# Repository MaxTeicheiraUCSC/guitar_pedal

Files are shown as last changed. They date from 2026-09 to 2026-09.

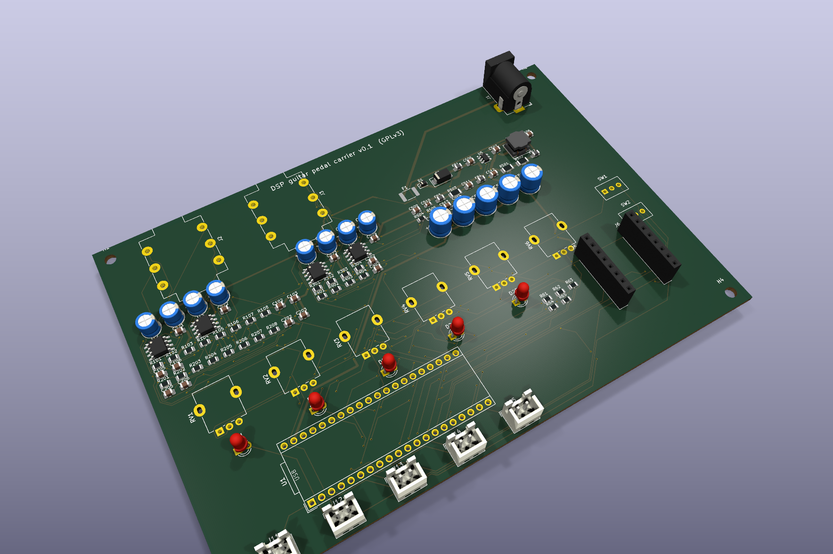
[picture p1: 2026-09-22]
hardware/kicad/out/pedal_3d_iso.png

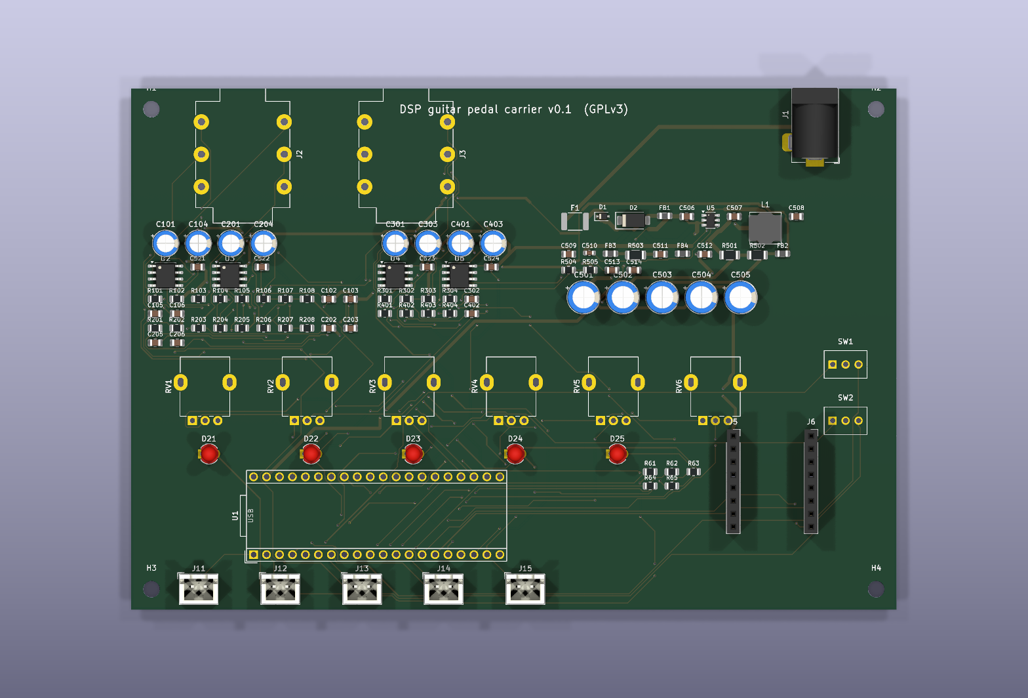
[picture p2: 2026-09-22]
hardware/kicad/out/pedal_3d_top.png

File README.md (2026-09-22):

# guitar_pedal — DSP multi-effect (tremolo · delay · reverb · fuzz)

Daisy Seed3 + ESP32-C3 stereo pedal with a reorderable four-effect chain, five
momentary footswitches, a shared six-knob bank, global high/low-cut toggles, and
BLE-MIDI / WiFi web-UI control. Design rationale, research and the phased plan are
in [`docs/design.md`](docs/design.md); the control protocol in [`docs/midi-map.md`](docs/midi-map.md).

```
firmware/dsp/      portable DSP core (header-only C++17) — shared by the pedal and the emulator
firmware/daisy/    Seed3 wrapper: audio callback, switches, knobs, UART-MIDI, presets   [unverified: no ARM toolchain here]
firmware/esp32/    C3 bridge: BLE-MIDI + WiFi AP web UI ⇄ UART-MIDI                   [unverified: no ESP toolchain here]
web/               single-file web UI served by the ESP32
emulator/          macOS emulator: `emu` offline CLI, hardware model, JUCE front panel (Standalone + VST3), tests
hardware/spice/    ngspice reference of the Seed3 instrument I/O stages + validation harness
hardware/kicad/    carrier board (not started)
docs/              design.md, midi-map.md
```

## Build & test (macOS)

```sh
cd emulator && cmake -B build -DCMAKE_BUILD_TYPE=Release && cmake --build build -j8
./build/dsp_tests                                   # 45 property tests
./build/emu --list                                  # parameter tables + CC numbers
./build/emu --in guitar.wav --out fx.wav --enable 0,1,2,3 --order 3,0,1,2 --hw --cpu
cmake -B build-juce -DPEDAL_BUILD_JUCE=ON && cmake --build build-juce -j8   # JUCE app + VST3 (fetches JUCE 8.0.9)
cmake -B build-juce -DPEDAL_BUILD_JUCE=ON -DPEDAL_HARNESS=ON && ./build-juce/juce/PedalHarness_artefacts/Release/PedalHarness   # in-process UI/audio stress test
cd ../hardware/spice/validate && python3 run_all.py # simple model vs ngspice → out/report.md
```

Handover: **[`docs/STATUS.md`](docs/STATUS.md)** (what is and is not verified, next steps) and
**[`docs/LEARNINGS.md`](docs/LEARNINGS.md)** (the non-obvious things this cost time to find).

## Status (2026-09-22)

- DSP core, emulator CLI, property tests, SPICE reference and validation harness: **done and passing**.
- Validation found and fixed a real error in the hand-derived analog model (input gain −6.2 dB, not −4.6 dB)
  and shows the codec's ±1.8 V limit is reached at ≈3.7 V pk at the jack, before the op-amps clip
  → the carrier board gets Schottky clamps at the codec input.
- JUCE front panel: builds Standalone + VST3 (AU needs full Xcode). Default source is an embedded CC0 clean-guitar loop (`emulator/assets`), so no interface is needed to audition; live input is a menu choice. `PedalHarness` drives the real processor + editor with concurrent audio at 44.1/48/96 kHz and passes.
- Daisy / ESP32 firmware: written, **not compiled** (toolchains not installed on this machine).
- KiCad carrier board: generated from one netlist, routed, 0 DRC errors with schematic parity; gerbers/STEP/BOM in `hardware/kicad/out/`.
- Windows VST3 v0.1.3 links the CRT statically and ships an installer — earlier builds needed the VC++ redistributable and failed to load without it.
- Hardware: nothing fabricated. First hardware task is the Phase A bench measurement in `docs/design.md` §11.
- A project guard (`.claude/settings.json` + `.claude/hooks/guard.py`) confines Claude Code sessions in this repo to this repo; see `docs/STATUS.md`.

## Windows / macOS binaries

`.github/workflows/build.yml` builds the emulator on `windows-latest` (MSVC) and `macos-latest`, runs the
DSP tests, and uploads `PedalEmu-windows-x64.zip` (installer + PedalEmu.vst3 + standalone) and the setup .exe and `PedalEmu-macos.zip`
as workflow artifacts; pushing a tag `v*` publishes them as a GitHub Release. Windows install/troubleshooting: `docs/WINDOWS-INSTALL.md`. The Windows job also builds an
Inno Setup installer, checks the binaries have no dynamic MSVC-runtime dependency, and re-validates
the plugin after extracting the shipped zip. Local Windows build:
`cd emulator && cmake -B build -DPEDAL_BUILD_JUCE=ON && cmake --build build --config Release --target PedalEmu_Standalone PedalEmu_VST3`
(Visual Studio 2022 Build Tools; JUCE 8.0.9 is fetched by CMake). The Windows build has only been
exercised in CI — see the Actions tab for the current status.

License: GPLv3 (see `LICENSE`) — this is the free JUCE tier and permits the GPL reverb algorithms.

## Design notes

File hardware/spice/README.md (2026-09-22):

# hardware/spice — ngspice reference for the analog I/O stages

Netlists transcribed from the Seed3 datasheet instrument-level circuits
(Fig 3.4 input, Fig 3.5 output, OPA1652 on +9 V, AREF bias 4.5 V):

- `input_stage.cir` — jack tip → codec pin. Stimulus and output paths are
  substituted by `validate/run_spice.py` (`{STIM}`, `{OUT}`, `{TSTEP}`, `{TSTOP}`, `{MODELS}`).
- `output_stage.cir` — DAC → output jack into a 1 MΩ ∥ 500 pF amp input.
- `pickup_loading.cir` — standalone AC check of pickup/cable resonance into the 1 MΩ input.
- `models/` — op-amp models (see `models/README.md`: the TI model is not bundled).

Topology notes (from reading the datasheet drawing, not the text dump):
- The 10 kΩ at the jack is on the **tip-normal** contact — it grounds an unplugged
  input and is out of circuit with a plug inserted, so Zin is the 1 MΩ bias resistor.
- The 3k3/4k7 divider sits between the buffer and the second stage: gain 0.5875,
  RC corner (3k3‖4k7)·1 nF ≈ 82 kHz. The 4k7 goes to ground, so the DC at that node
  is 0.5875 × 4.5 V; the 10 µF re-couples to the second stage's 4.5 V reference.
- Second stage is inverting, 10k/10k ‖ 330 pF (48 kHz); output RC 100 Ω/33 nF (48 kHz).
- Codec input: AC coupled, 20 kΩ typical. **No clamp is drawn**; the codec's
  ±1.8 V absolute maximum is checked by measurement in the validation report.
- Output: inverting 33k/15k = −2.2 ‖ 100 pF (48 kHz), 100 Ω series, 10 µF, 10 kΩ.

Unknowns carried as assumptions (flagged in the report): AREF bias exactly 4.5 V and
stiff; codec coupling capacitor value (4.7 µF assumed); codec input capacitance ignored.

Validation harness: see `validate/README.md`.

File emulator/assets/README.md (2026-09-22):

# assets

- `test_loop.wav` — 40 s clean electric-guitar loop (Am–F–C–G arpeggios then strums + melody,
  96 bpm, seamless), mono 44.1 kHz 16-bit, peak 0.5. Built by `make_test_loop.py` from the
  FreePats **FSBS Electric Guitar Clean** note samples (real Fender DI recordings), released under
  **CC0 1.0** — see `FREEPATS-LICENSE-CC0.txt` and https://freepats.zenvoid.org/ElectricGuitar/.
  The loop itself is therefore also CC0. It is embedded in the PedalEmu app as the default source.
- `test_e_gsharp.wav` — 10 s loop: E3 (with E2 under it) for 5 s, then G♯3 for 5 s, each plucked at 0 and 2.5 s. Same CC0 samples. **Default source in PedalEmu.**
- `test_emaj7_arp.wav` — 10.4 s loop: E major 7 arpeggio (E3 G♯3 B3 D♯4 E4 D♯4 B3 G♯3) in plucked eighth notes at 92 bpm with a low E2 under each bar. Same CC0 samples.
- Regenerate: download the `.flac` files from https://github.com/freepats/electric-guitar-FSBS-clean/tree/main/samples/bridge/small
  into a folder and run `python3 make_test_loop.py <folder>` (needs ffmpeg).

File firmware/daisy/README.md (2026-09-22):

# firmware/daisy — Seed3 wrapper (unverified)

`main.cpp` binds the portable core in `../dsp` to the Daisy Seed3: audio callback,
footswitch gestures, knob bank with soft take-over, global HP/LP toggles, LEDs,
UART-MIDI link to the ESP32-C3, QSPI presets, CPU load logging, DFU gesture.

Status: **not compiled** in this repo yet — there is no `arm-none-eabi-gcc` on the
dev machine. Expect API-name fixes against the libDaisy version you check out
(`UartHandler` FIFO receive, `PersistentStorage`, `Switch::TimeHeldMs`).

Build: `git clone --recursive https://github.com/electro-smith/libDaisy third_party/libDaisy && make -C third_party/libDaisy && make`
Flash: hold fx1 + fx4 for 2 s (or BOOT+RESET) then `make program-dfu`. If you switch to
`APP_TYPE=BOOT_SRAM` (bigger images), flash the Daisy bootloader once with `make program-boot`;
the fx1+fx4 gesture then drops into that bootloader instead of the ROM DFU.

First hardware measurements to take (docs/design.md §12): `cpu avg/max` from the
serial log with all four effects on, fuzz at 4×; if max > 75 % drop the fuzz to 2×
(`Oversample` param) before touching anything else.

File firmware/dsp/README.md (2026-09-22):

# firmware/dsp — portable DSP core

Header-only C++17, no heap in the audio path, no exceptions/RTTI, no libDaisy
dependency. Compiled unchanged into:

- `firmware/daisy/` (STM32H750, arm-none-eabi-gcc, buffers in SDRAM via the `Allocator`)
- `emulator/` (macOS, clang, buffers on the heap)

| header | contents |
|---|---|
| `pedal/core.h` | `Frame`, `Allocator`, `ParamDesc`, `Smoother`, `Biquad`, `Lfo`, `DelayLine` |
| `pedal/effect.h` | `Effect` interface (params, enable with trails, tempo hook) |
| `pedal/tremolo.h` | LFO tremolo, harmonic mode, stereo phase |
| `pedal/delay.h` | 2 s stereo fractional delay, filtered/saturated feedback, wow/flutter, ping-pong, subdivisions |
| `pedal/reverb.h` | Dattorro plate |
| `pedal/oversampler.h` | polyphase FIR 1x/2x/4x |
| `pedal/fuzz.h` | oversampled ADAA waveshaper, tilt tone, gate |
| `pedal/pedal.h` | `Pedal`: chain order, global HP/LP toggles, tap tempo, presets, listener |
| `pedal/midi.h` | MIDI parser + the control map shared with the ESP32 bridge |

Rules: every effect's `process()` is called every block so it can render trails;
state-less effects return immediately when disabled. Parameter changes are
smoothed inside the effects; the caller may set them from any thread as long
as each `setParam` is a single float store.

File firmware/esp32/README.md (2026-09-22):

# firmware/esp32 — radio co-processor (unverified)

ESP32-C3 SuperMini. BLE-MIDI peripheral + WiFi AP (`pedal` / `guitarfuzz`) serving
`../../web/index.html` over HTTP with a WebSocket at `/ws`; everything is translated
to the MIDI map in `docs/midi-map.md` and forwarded to the Daisy on UART1.

Status: **not built** here (no PlatformIO on the dev machine). Library names in
`platformio.ini` are the current ones on the registry; pin numbers are the C3
SuperMini's UART1 defaults — check against your board.

Wiring: C3 TX (GPIO21) → Seed3 D14 (USART1 RX); C3 RX (GPIO20) ← Seed3 D13 (USART1 TX); common GND. Both 3.3 V logic.

Web UI: `cp ../../web/index.html data/ && pio run -t uploadfs` (`data/` is a copy made at upload time; `web/` is the source).
OTA: `pio run -t upload --upload-port pedal.local` once connected to the AP.

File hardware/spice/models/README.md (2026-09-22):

# SPICE models

| file | what | status |
|---|---|---|
| `opa1652_behavioral.lib` | behavioral op-amp with OPA1652 datasheet numbers (GBW, slew, rail-to-rail limits, input C) | **substitute** — used by default |
| `opa1652_ti.lib` | TI's official macromodel | not included (licence click-through); download from ti.com/product/OPA1652 and set `OPAMP_MODEL = "ti"` in `../validate/config.py` |

The behavioral model reproduces small-signal bandwidth, slew limiting and rail
clipping, which are the effects the emulator's simple model is being checked
against. It does not model noise, offset, output current limit, or the real
open-loop phase margin, so results within ~0.1 dB / a few degrees at 20 kHz are
already at the limit of what this substitute can claim.

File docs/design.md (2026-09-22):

# Multi-effect DSP guitar pedal — research findings and design plan

## Context

Max wants a one-off guitar pedal with tremolo, delay, reverb and fuzz, all implemented in DSP, built on a dev board rather than a bare-MCU custom design. Requirements gathered in Q&A:

- All four effects digital (no analog fuzz stage), each with its own footswitch, running simultaneously, with the chain order re-arrangeable.
- Stereo-capable I/O (2× TRS jacks, mono-compatible), buffered bypass through the DSP (no relay), 9 V centre-negative barrel power, no internal supply.
- Wireless control via a web page served by the pedal **and** BLE-MIDI; firmware updates over USB.
- Physical: 4 effect footswitches + tap-tempo footswitch, a shared bank of ~6 knobs with effect-select, two physical toggles for global high-cut / low-cut (corner frequency set in the app), per-effect HP/LP cuts in the app only.
- Budget ≈ $250 for parts; custom carrier PCB is in scope.

The directory `/Users/maxteicheira/Documents/Claude/guitar_pedal` is empty, so implementation starts from zero. This plan records the research and the recommended architecture; the deliverables of the implementation phase are a project README, a block diagram/BOM, KiCad schematic for the carrier board, Daisy firmware, and ESP32 firmware.

---

## 1. Platform decision

**Recommended: Electro-Smith Daisy Seed3 (audio DSP) + ESP32-C3 module (radio co-processor), linked by UART carrying MIDI.**

| Candidate | DSP | Radio | Verdict |
|---|---|---|---|
| **Daisy Seed3** — STM32H750 Cortex-M7 @480 MHz, TI TAC5242 codec, 192 kHz/32-bit, 64 MB SDRAM, 8 MB QSPI, USB-C DFU, $29.99, in stock | Strong; libDaisy + DaisySP; large pedal ecosystem (Terrarium, Hothouse, Funbox, GuitarML) | none | **Pick.** Pin-compatible with all existing Seed pedal designs. |
| Teensy 4.1 + audio shield | Strongest CPU (600 MHz) | none | Viable, but 16-bit SGTL5000 shield and a smaller pedal ecosystem. |
| ESP32-S3 + external codec | Weak for reverb + delay + oversampled fuzz simultaneously; no FPU-heavy DSP headroom | built-in | Reject as sole processor. |
| RP2350 | No hardware FPU parity with M7; small ecosystem for audio | none | Reject. |

Why two chips: the Seed3 has no radio; ESP32 alone can't carry the DSP load. Prior art for exactly this split exists (`TMANTsmith/daisy-esp32-guitar-pedal`, ESP32-C6 + Daisy, web UI on the ESP32).

Why UART not SPI/USB: ESP32-S2/S3 share one USB PHY between USB-host and the radio, so USB between the two boards is a coexistence trap. UART at 115200–921600 baud is plenty for control traffic and the Seed3 has free USARTs (D13/D14 = USART1).

Why ESP32-C3 over S3: the load is a web server + BLE-MIDI + UART bridge, which the single-core C3 handles; it is cheaper and smaller (SuperMini form factor, ~18 mm wide). Use the **S3 or C6** only if a later OLED or heavier UI is wanted. Note: simultaneous WiFi + BLE on ESP32 works but is finicky in Arduino — plan to run the radio via ESP-IDF or Arduino-on-IDF with the coexistence config enabled, and default to **BLE on, WiFi AP started on a long-press** so they rarely fight.

## 2. Block diagram

```
 9V DC barrel (centre −) ──► reverse-polarity + polyfuse + filter (Seed3 datasheet Fig 1.1) ──┬──► +9V_A analog rail (op-amps only)
                                                                                              └──► buck 9V→5V (≥600 mA) ──┬──► LC/RC filter (Fig 1.4) ──► Seed3 VIN
                                                                                                                          └──► ESP32-C3 5V pin ──► its own 3V3 LDO

 IN (TRS) ─► 1 MΩ JFET/OPA1652 buffer ×2 (L/R) ─► level shift + anti-alias RC ─► Seed3 Audio In 1/2
 Seed3 Audio Out 1/2 ─► OPA1652 output stage ×2 (+9 V rail, gain ≈ ×2, 100 Ω out) ─► OUT (TRS)
                        (TRS ring: switch contact on IN jack → GPIO "stereo cable present")

 Seed3 GPIO/ADC:
   ADC0–5  : 6 knobs (B10k to 3V3A)
   D-pins  : 5 momentary SPST footswitches (to GND, internal pull-up)
             2 × ON-OFF-ON toggles (global HP / LP: off / low / high)
             5 LEDs (4 effect state, 1 tempo blink)  — or 4 RGB LEDs so colour = which effect the knob bank edits
   USART1  : ESP32-C3 (3.3 V logic both sides, TX/RX only)
   USB-C   : DFU firmware update (panel-mount USB-C extension on the enclosure side)

 ESP32-C3: WiFi AP + captive web UI (HTTP + WebSocket), BLE-MIDI peripheral, UART-MIDI bridge to Seed3, OTA optional.
```

## 3. Analog front-end / back-end (the only analog design work)

Facts from the Seed3 datasheet (v1.x, pulled 2026-09-21):
- Codec inputs are AC-coupled, **3.6 Vpp typical, ±1.8 V absolute max**. Line input Z is 20 kΩ; outputs 0 dBFS @ 1 Vrms, 100 Ω.
- The datasheet's *Instrument Level* reference circuit (Fig 3.4/3.5, used on the Seed3 Pedal Dev Kit) is: input → 1 MΩ to bias, 10 kΩ pull-down on tip, 100 pF RF cap, OPA1652 unity buffer on a **+9 V single rail** with a mid-rail `AREF_AUDIO_BIAS`, second OPA1652 inverting stage (3k3 / 10k) with 33 nF / 330 pF anti-alias filtering; output stage OPA1652 non-inverting (15 kΩ / 33 kΩ), 10 µF coupling, 100 Ω series, 10 kΩ load.

Design rules to carry into the schematic:
1. **Copy Fig 3.4 / 3.5 verbatim, per channel.** It gives 1 MΩ input impedance, instrument-level headroom and the correct anti-alias filtering; the datasheet publishes its noise/THD plots.
2. **Clamp the codec input.** A +9 V-rail op-amp can swing ~8 Vpp; the codec limit is ±1.8 V. Add a series 100 Ω + Schottky clamps (BAT54S) to AGND/+3V3A at Audio In 1/2, or pick the second-stage gain so full-scale is reached before the op-amp clips. Verify with a hot humbucker/active bass before finalising.
3. **One ground.** AGND and DGND tied at the Seed, single star ground at the DC jack, per datasheet.
4. **Power filtering** exactly as datasheet Fig 1.1 (ferrite + NSR1020 reverse protection + 3R3/100 µF RC on the analog rail). Keep the ESP32 buck on its own filtered branch; radio TX bursts must not reach +9V_A.
5. **Stereo detection**: use the ring-switch on the IN jack; firmware runs dual-mono when a TS plug is present.
6. No relay: bypass is a software pass-through with the effect chain muted, which is what allows delay/reverb trails.

## 4. Footswitches (research summary)

Because bypass is buffered through the DSP, every footswitch carries only a 3.3 V logic level — **electrical life rating is irrelevant; mechanical life and feel are the spec**. Momentary switches also give hold/double-tap gestures for free (effect-select for the knob bank, tap tempo, DFU entry, WiFi-AP start).

| Option | Type | Published life | Notes |
|---|---|---|---|
| **Generic "soft touch" SPST momentary NO** (Guitar Pedal Parts, Love My Switches "Pro-Grade", Daier/Gebildet) | SPST momentary, solder lug | ~50 000 cycles (electrical); users report >100 k | $3–6 each. Quiet, smooth. **Recommended for 5 switches at this budget.** |
| **Lehle SPST momentary soft-click "long life"** (Amplified Parts) | SPST momentary, gold contacts | ≥1 000 000 cycles mech+elec | ~$15–20 each. Upgrade for the 4 effect switches if budget allows. |
| Gorva Design Mechano soft-click | 3PDT latching | 30 000 cycles | Wrong type for this design (latching, MCU can't read state changes cleanly, no gestures). Listed for comparison. |
| Industrial momentary (RS PRO / Mouser foot switches) | SPST, die-cast | often 100k–1M | Too large for a stompbox top; skip. |

Firmware: 5–10 ms software debounce, hold = 500 ms, double-tap window 300 ms. Reserve: hold **tap** = enter effect-select mode; hold **fx1 + fx4** for 2 s = DFU mode (Hothouse convention); hold **tap** 3 s = toggle WiFi AP.

Global HP/LP toggles: 2 × ON-OFF-ON miniature toggles (wiring per the original Seed datasheet Fig 1.9 — two GPIOs with pull-ups, centre = both open; e.g. 2MS3T1B1M2QES). Centre = off; up/down select the two corner frequencies stored from the app.

## 5. DSP methods — analog vs. digital per effect

| Effect | Analog method (for reference) | Chosen digital method | Library / prior art |
|---|---|---|---|
| **Tremolo** | Optical (LDR + lamp, Fender), bias-wiggle, JFET VCA; harmonic tremolo splits bands and modulates anti-phase | LFO × gain, with shape (sine/tri/square/opto-curve) and depth; add **harmonic tremolo** mode (crossover + anti-phase LFOs) — cheap, distinctive | `DaisySP::Tremolo`, `Oscillator` |
| **Delay** | BBD (MN3005) with companding and clock-noise filtering; tape (wow/flutter, head EQ) | Fractional (Hermite/allpass-interpolated) delay line in SDRAM, up to ~2 s stereo; feedback path with the per-effect HP/LP; tape/BBD flavour via wow-flutter LFO + soft-clip + low-pass in feedback; tap tempo with subdivisions; ping-pong when stereo | `DaisySP::DelayLine`, bkshepherd `GuitarPedal` delay modules |
| **Reverb** | Spring tank (transducer + springs), plate | Start with **DaisySP `ReverbSc`** (cheap, good); upgrade path is **CloudSeed-Daisy** (benjaminvdb, runs full-size programs on H750 using MDMA streaming into TCM) or a Dattorro plate. Per-effect HP/LP in the tail, pre-delay, decay, mix. Spring emulation later if wanted (Dattorro-style with dispersive allpass chain). | `DaisySP::ReverbSc`, `benjaminvdb/cloudseed-daisy`, GuitarML/Funbox reverbs |
| **Fuzz** | Fuzz Face (2-Ge/Si transistor feedback pair, input-impedance interaction), Big Muff (4-stage clipping), Tone Bender | Two tiers: (a) **waveshaper fuzz** — input gain → asymmetric tanh/hard-clip with bias & gate → tone (tilt EQ), with **2–4× oversampling + antiderivative anti-aliasing (ADAA)**; (b) **circuit-modelled Fuzz Face** via wave-digital filter (`chowdsp_wdf`, header-only C++, CCRMA WDF Fuzz Face reference) if CPU allows. Neural (LSTM) fuzz is the GuitarML route but training is out of scope for v1. | `chowdsp_wdf`, ADAA (Parker/Zavalishin), GuitarML |
| **HP/LP cuts** | Passive RC / active Sallen-Key | 2nd-order Butterworth biquads (`DaisySP::Svf` or `Biquad`), per-effect (in delay/reverb feedback) and global on output | DaisySP |

Sample rate: run the codec at **48 kHz**, block size 32–48 samples (≈0.7–1 ms per block; total round-trip latency target < 3 ms incl. codec group delay). Oversample only inside the fuzz. 96/192 kHz buys nothing for guitar and quadruples reverb/delay cost.

### CPU budget (480 MHz M7, 48 kHz, stereo) — measure with `daisy::CpuLoadMeter`, targets below are the pass/fail gates

| Block | Target | Fallback if over |
|---|---|---|
| Tremolo (stereo) | < 2 % | — |
| Delay 2 s stereo, interpolated, feedback filters | < 8 % | Linear interpolation; mono delay line + stereo spread |
| Reverb `ReverbSc` | < 15 % | — ; CloudSeed target < 40 % with MDMA streaming, else use a smaller CloudSeed program |
| Fuzz, 4× OS + ADAA, stereo | < 15 % | 2× OS; mono fuzz constrained to before first stereo effect |
| WDF Fuzz Face, stereo | < 30 % | Mono, or waveshaper tier only |
| Control/UART/UI | < 3 % | — |
| **Total headroom** | ≤ 75 % | — |

### Stereo + reorderable chain decision
Process the whole chain in stereo always (2 channels through every effect). This is the simple, correct option and is what makes "fuzz after stereo delay" legal. If the fuzz WDF tier blows the budget, the fallback is a firmware rule that mono-only effects must sit upstream of the first stereo-widening effect (delay/reverb) — the app enforces this in the reorder UI.

## 6. Control architecture

Single protocol everywhere: **MIDI**.
- Knobs, footswitches, toggles → Daisy directly (lowest latency).
- Web UI (WebSocket JSON) and BLE-MIDI both terminate on the ESP32-C3, which converts them to MIDI bytes over UART to the Daisy; Daisy sends state changes back the same way so the web UI and BLE clients stay in sync.
- Parameters = MIDI CC (14-bit CC pairs for time/frequency where 128 steps is too coarse). Chain order, presets, HP/LP corner frequencies = SysEx. Tap tempo = MIDI Clock or a CC.
- **Knob soft-takeover**: after an app/MIDI change, a physical knob does nothing until it passes through the current value. Required because pots are absolute.
- Effect-select for the knob bank: hold TAP then press an effect switch; LED colour/blink shows which effect is bound.
- Presets stored in Seed3 QSPI (libDaisy `PersistentStorage`), ~8 slots; recalled via app, BLE-MIDI Program Change, or double-tap gestures.
- No display was chosen: chain order, preset name and per-effect cut state are visible only in the app; LEDs show effect on/off and tempo.

## 7. Firmware update paths

- **Daisy Seed3**: USB DFU (`dfu-util` or the Electro-Smith web programmer). Panel-mount USB-C passthrough on the enclosure so the box never opens. Enter DFU via the fx1+fx4 hold gesture (libDaisy `System::ResetToBootloader()`) — no need to reach the BOOT button.
- **ESP32-C3**: USB-serial flashing through a second panel USB-C, or **WiFi OTA** (ArduinoOTA / esp_https_ota) once the AP is up. Recommended: OTA as the normal path, USB as recovery.
- Optional later: ESP32 pulls a Daisy firmware image over WiFi and flashes the Daisy through its UART bootloader (STM32 system bootloader supports UART), making the whole pedal updatable wirelessly. Not v1.

## 8. Power budget (9 V barrel, centre negative)

| Load | Rail | Estimate | Source |
|---|---|---|---|
| Seed3 (480 MHz, codec, SDRAM) | VIN 9 V | 100–140 mA | community measurements at 5 V USB; Seed3 regulator dissipation is higher at 9 V — datasheet warns "higher input voltages can increase heat" |
| ESP32-C3, WiFi TX bursts | 3.3 V via buck | 30 mA idle, 250–350 mA peaks | Espressif datasheet class figures |
| 4× OPA1652 + bias | +9 V | ~10 mA | |
| LEDs (5) | 3.3 V | ≤ 25 mA | |
| **Total** | | **~250 mA typical, ~450 mA peak from 9 V** | |

Implications: many isolated pedalboard supply outputs are 100–200 mA; state clearly that this pedal needs a **≥500 mA 9 V output** (e.g. a "high-current" tap). Put a 1 A polyfuse + reverse-protection at the jack. Decide in bench testing whether to feed Seed3 VIN from 9 V directly (simplest, more heat in its LDO) or from the 5 V buck (cooler; buck noise must then be filtered per datasheet Fig 1.4 — 1 mH/3R3 + 100 µF). Recommendation: **feed Seed3 from the 5 V buck**, filtered, and keep the +9 V rail for op-amps only.

## 9. Enclosure and BOM sketch (≈ $250)

| Item | Approx | Notes |
|---|---|---|
| Daisy Seed3 | $30 | |
| ESP32-C3 SuperMini | $5 | |
| Custom carrier PCB (JLCPCB, 2-layer, 5 pcs) | $30 | Seed3 socketed on headers; op-amps SMD |
| 5× soft-touch SPST momentary footswitches | $25 (generic) / $80 (Lehle ×4 + 1 generic) | |
| 6× Alpha 9 mm B10k pots + knobs | $15 | |
| 2× ON-OFF-ON toggles | $6 | |
| 2× TRS 1/4" jacks (Neutrik NMJ6HCD2 or Lumberg) + DC jack | $12 | |
| Op-amps (OPA1652 ×2), buck module, passives, LEDs, USB-C panel mounts | $30 | |
| Enclosure Hammond 1590XX (145×121×39 mm) or 1590DD (188×120×56 mm), powder-coated, drilled | $35–45 | **Open layout check**: 5 footswitches in one row across a 1590XX is ~29 mm pitch — too tight to stomp (40–50 mm is normal). Either 4 effect switches in a row + TAP on a second row (1590XX) or a single row on a 1590DD. 125B is too small either way. |
| **Total** | **≈ $190–245** | |

## 10. Risks and mitigations

1. **Radio EMI into a 1 MΩ input.** Put the ESP32 at the far end from the input jack, antenna facing the enclosure wall, keep the input trace short, shielded input wire, ferrite on the ESP32 supply. Test: noise floor with WiFi AP on vs off.
2. **CPU budget.** Gate each effect on the CPU table in §5 before integration; reverb tier and fuzz tier are the two swap-outs.
3. **WiFi/BLE coexistence on ESP32.** Default BLE-only; WiFi AP on gesture; use ESP-IDF coexistence settings. Fallback: WiFi only when a phone is actively connected.
4. **Codec input overdrive.** Clamp diodes + gain structure (§3 rule 2), decided by the SPICE reference sim in §10b item 6 before the PCB is ordered.
5. **Knob/app fights.** Soft-takeover (§6).
6. **9 V supply headroom.** Document the ≥500 mA requirement; consider a 9–18 V-tolerant buck so a 12 V/18 V tap also works (Seed3 VIN tolerates 17 V; op-amps do not need it).
7. **Seed3 availability.** Currently in stock (179 units on 2026-09-21); an original Seed (rev 7) is a pin-compatible fallback with a PCM3060 codec and the same datasheet limits.

## 10b. Software emulator of the pedal (added per request)

Goal: run the complete pedal — the same DSP code, the same control model (dials, footswitches, toggles, chain order), the same MIDI/SysEx protocol — on the Mac, with audio in/out, so effects can be developed, auditioned and regression-tested before and alongside the hardware.

Architecture — **one DSP core, two hosts**:

```
 firmware/dsp/          pure C++, no libDaisy dependency: effects, chain, parameter model, MIDI/SysEx parser,
                        preset serialisation. Fixed-size float[2] frames, block-based, sample-rate agnostic.
 firmware/daisy/        thin libDaisy wrapper: codec callback → dsp core; GPIO/ADC → parameter model; UART → MIDI parser.
 emulator/              host wrapper: same dsp core compiled natively (arm-none-eabi vs clang), driven by
                        a virtual front panel and real audio I/O.
```

Emulator components:
1. **Audio engine**: CoreAudio/PortAudio (via JUCE or RtAudio) for live guitar through an interface, plus offline mode (`emu --in guitar.wav --out result.wav --preset x.json`) for deterministic regression tests.
2. **Virtual front panel** (decided: **JUCE standalone app + VST3/AU plugin**, same code): 6 dials, 5 footswitches (click = tap, hold = gesture), 2 HP/LP toggles, LEDs, stereo/mono jack state — laid out exactly like the enclosure drawing. The plugin build lets you A/B in a DAW. The emulator additionally exposes the ESP32's WebSocket endpoint so the pedal's web UI can be tested against it (secondary, not the primary panel).
3. **Hardware model layer** (what makes it an *emulator* rather than a plugin): 
   - Codec model: 48 kHz block size = firmware block size, AC coupling, ±1.8 V clip, quantisation to 24/32-bit, measured codec noise floor injected (optional).
   - Analog I/O stage model: 1 MΩ input / OPA1652 stages from §3 as biquads with the datasheet corner frequencies and soft-clip at the rails, so headroom problems are heard on the Mac first. Coefficients derived from an **ngspice** simulation of the §3 schematic (`hardware/spice/`), which also serves as the design check for the analog stage.
   - Pot model: 10k linear/log taper + ADC 12-bit quantisation + smoothing identical to firmware; soft-takeover logic runs here too.
   - CPU model: report per-block cost ratio scaled by a measured Mac↔M7 factor as an early-warning of the §5 budget (not cycle-accurate; the real check is `CpuLoadMeter` on the Seed3).
4. **Control plumbing**: virtual UART — the ESP32 bridge code talks to the emulator over a local TCP socket or a real USB-serial ESP32-C3 on the desk, so BLE-MIDI/WiFi control is testable end-to-end without the Daisy.
5. **Tests**: golden-file audio tests per effect (impulse/sine/guitar clip → compare spectra, aliasing level in fuzz, delay time accuracy vs tap tempo, reverb RT60), run in CI on the host build. Comparisons are within tolerance (spectral/RMS error bounds), not byte-for-byte: the M7 single-precision FPU and clang on Apple Silicon differ in FMA contraction and rounding.

6. **Simple-model vs. full-SPICE validation harness** (`hardware/spice/validate/`). The emulator's analog layer (item 3) is a deliberately minimal "ideal" model: biquads + soft-clip. It is only trustworthy if checked against a full-fidelity simulation of the real circuit, so:
   - **Reference**: ngspice transient simulation of the complete §3 schematic per channel — OPA1652 vendor SPICE macromodel, real bias network, coupling caps, 1 MΩ/10 kΩ input network, a pickup source model (series L ≈ 2–4 H, R ≈ 6–10 kΩ, parallel C ≈ 100 pF, so cable/input loading is included), codec input as 20 kΩ ∥ clamp diodes, output stage into 10 kΩ ∥ 100 pF and into a 1 MΩ amp input.
   - **Stimulus set** (identical WAV files fed to both): log sine sweep 10 Hz–24 kHz at −20 dBFS-equivalent; 1 kHz tones stepped 100 mVpp → 8 Vpp (to find where the op-amp stage vs. the codec clamp limits first); square/impulse for transient/slew behaviour; a DI guitar clip.
   - **Metrics** (Python, `numpy`/`scipy`; ngspice driven via `PySpice` or raw `.cir` + `wrdata`): magnitude/phase response error (target < 0.5 dB / 5° 20 Hz–20 kHz), THD vs. input level, clip onset level and clip shape (waveform correlation), DC offset at the codec pin, output stage load sensitivity.
   - **Loop**: where the simple model misses (typically clip knee shape, sub-20 Hz coupling-cap corner interaction, slew on square edges) fit its parameters to the SPICE result — soft-clip curve fitted to the SPICE transfer curve, biquad corners re-derived — and re-run until within tolerance. The fitted parameters are committed as the emulator's hardware constants, with the SPICE run recorded as the reference.
   - **Also a design tool**: the same reference sim answers the §3 rule-2 question (do we need clamp diodes, or does gain structure alone keep the codec under ±1.8 V?) before the PCB is ordered, and gets re-run against bench measurements of the real board in Phase B (SPICE ↔ hardware ↔ simple model, three-way).
   - Real-time SPICE-in-the-loop remains out of scope; this is an offline comparison.

Memory abstraction: any effect needing large delay memory (delay lines, CloudSeed's MDMA/TCM streaming) takes its buffers through an allocator interface in the DSP core — the Daisy wrapper supplies SDRAM (`DSY_SDRAM_BSS`) and TCM windows, the host supplies heap. Without this the reverb upgrade path and the emulator are mutually exclusive.

Not in scope: cycle-accurate STM32 emulation (QEMU/Renode) — high effort, no benefit for audio; the dsp-core split above gives numerically equivalent behaviour within tolerance where it matters.

License: the whole project is **GPLv3**. This is the free JUCE tier for a one-off personal build and it unlocks the GPL reverbs (Dattorro plate, CloudSeed) that the bkshepherd project has to disable.

## 11. Phased build

**Phase 0 — emulator first (no hardware needed)**
0. Scaffold repo; write `firmware/dsp/` core + `emulator/` host (audio I/O, virtual panel, offline render, golden tests). All four effects and the chain are developed and auditioned here. ngspice model of the analog I/O stage feeds the emulator's hardware layer.

**Phase A — bench prototype (dev boards, breadboard/proto)**
1. Seed3 on a breadboard with the datasheet instrument I/O circuit, one channel; verify loopback audio, noise floor, headroom.
2. Port/write the four effects one at a time in libDaisy/DaisySP; log `CpuLoadMeter` per effect; build the reorderable chain (array of effect pointers, stereo `float[2]` frames, per-effect bypass with trails).
3. ESP32-C3: BLE-MIDI + UART bridge to Daisy; then WiFi AP + captive web UI (single HTML/JS page with WebSocket, stored in SPIFFS/LittleFS); soft-takeover and SysEx preset/order messages.
4. Footswitch gesture layer, tap tempo, effect-select, LEDs.

**Phase B — carrier PCB (KiCad)**
5. Schematic: Seed3 socket, 2× stereo I/O stages, power section (reverse protection, filters, buck), ESP32-C3 socket, pots/switches/LEDs headers, USB-C passthroughs. Reuse Seed3 datasheet figures 1.1, 1.9, 3.4, 3.5 as-is.
6. Layout for 1590XX: input stage far from ESP32; star ground; test points on rails.
7. Order boards, assemble, bring-up with Phase A firmware.

**Phase C — enclosure and polish**
8. Drill template, labels, final firmware, presets, README with DFU/OTA instructions.

Repo layout to create: `docs/` (this research, block diagram, BOM), `hardware/kicad/` + `hardware/spice/` (ngspice analog stage), `firmware/dsp/` (portable DSP core), `firmware/daisy/` (libDaisy wrapper), `firmware/esp32/` (ESP-IDF or PlatformIO Arduino), `emulator/` (host app + tests), `web/` (UI source built into the ESP32 filesystem and served by the emulator).

## 12. Verification

- **Audio path**: sine loopback → measure round-trip latency (scope, expect < 3 ms at 48 kHz/32 samples), noise floor (target ≤ −90 dBFS A-weighted), THD at −6 dBFS, no clipping at codec with hot pickups.
- **CPU**: `CpuLoadMeter` max per block with all four effects on, stereo, worst-case settings (max delay time, max oversampling); must stay ≤ 75 %.
- **Power**: bench supply current at 9 V with WiFi AP active and a client connected; peak ≤ 500 mA; Seed3 and buck temperatures after 30 min.
- **EMI**: noise floor with WiFi on/off, BLE on/off; hum with single-coils.
- **Control**: BLE-MIDI from an iOS/macOS MIDI app changes parameters; web UI reorders chain and it audibly changes; knob soft-takeover behaves; presets survive power-cycle.
- **Switches**: debounce shows zero double-triggers over 200 presses; hold gestures reliable; DFU gesture enters bootloader and `dfu-util -l` sees the device.
- **Mono/stereo**: TS plug in IN → dual-mono; TRS → true stereo; ping-pong delay only in stereo.
- **Emulator fidelity**: simple analog model vs. full ngspice reference (§10b item 6) within 0.5 dB / 5° across 20 Hz–20 kHz and matching clip-onset level within 0.5 dB; golden-file effect tests pass on the host build; in Phase B the same stimulus set is played through the real board and compared three-way (SPICE ↔ hardware ↔ simple model).
- **Power section**: Seed3 fed from the filtered 5 V buck output boots reliably and the buck's switching noise is absent from the audio noise floor (compare against Seed3 on bench 5 V).

## Sources

- Seed3 product/docs: https://docs.daisy.audio/hardware/Seed3/ · https://daisy.audio/products/seed3 · datasheet https://daisy.nyc3.cdn.digitaloceanspaces.com/products/seed3/Daisy_Seed3_datasheet.pdf
- Original Seed datasheet (limits, codec app note): https://daisy.nyc3.cdn.digitaloceanspaces.com/products/seed/Daisy_Seed_datasheet.pdf
- Seed current draw thread: https://community.daisy.audio/t/power-consumption/4521
- 9 V to VIN thread: https://forum.electro-smith.com/t/connecting-9v-directly-to-daisy-seed/1279
- Instrument input thread: https://community.daisy.audio/t/instrument-input-for-daisy/9095
- Pedal hardware summary: https://community.daisy.audio/t/summary-of-daisy-seed-guitar-pedal-hardware-options/7336
- Hothouse: https://clevelandmusicco.com/hothouse-diy-digital-signal-processing-platform-kit/ · https://github.com/clevelandmusicco/HothouseExamples
- bkshepherd GuitarPedal (chain, presets, MIDI, tap tempo): https://github.com/bkshepherd/DaisySeedProjects/blob/main/Software/GuitarPedal/README.md
- Daisy + ESP32 pedal: https://github.com/TMANTsmith/daisy-esp32-guitar-pedal · https://community.daisy.audio/t/esp32-control-of-daisy-seed/1226
- CloudSeed on Daisy: https://github.com/benjaminvdb/cloudseed-daisy
- WDF Fuzz Face / chowdsp_wdf: https://github.com/Chowdhury-DSP/chowdsp_wdf · https://ccrma.stanford.edu/wiki/Wave_Digital_Filters_applied_to_the_Dunlop_%22Fuzz_Face%22_Distortion_Circuit · https://arxiv.org/pdf/2009.02833
- Antialiasing for distortion: https://www.kvraudio.com/forum/viewtopic.php?t=445438 · https://arxiv.org/pdf/2505.11375
- ESP32 BLE-MIDI: https://github.com/max22-/ESP32-BLE-MIDI · coexistence: https://esp32.com/viewtopic.php?t=16747
- ESP32 C3 vs S3 SuperMini: https://www.espboards.dev/blog/esp32-super-mini-comparison/
- Footswitches: https://www.amplifiedparts.com/products/footswitch-lehle-spst-momentary-soft-click-long-life · https://lovemyswitches.com/pro-grade-spst-momentary-foot-switch-normally-closed-soft-touch-solder-lug/ · https://guitarpedalparts.com/products/spst-momentary-soft-touch-foot-switch · https://www.amplifiedparts.com/products/footswitch-3pdt-g-rva-design-mechano-soft-click · https://forum.pedalpcb.com/threads/spst-footswitch-guidance.7701/

---

## Phase 0 results (2026-09-21)

Implemented: `firmware/dsp` core (all four effects, chain, cuts, tap tempo, presets, MIDI map),
`emulator/` (offline CLI + hardware model + 45 property tests + JUCE panel), `hardware/spice/`
(ngspice reference + validation harness). Findings that change the design:

1. **Input-stage gain is −6.2 dB, not −4.6 dB.** The second stage's 10 kΩ input resistor loads the
   3k3/4k7 divider (4k7 ‖ 10k). Net pedal gain jack→jack with the datasheet stages is ≈ 0.49 × (1.414/1.8) × 2.2 ≈ 0.85 (−1.4 dB); set `outputTrimDb` ≈ +1.4 dB in firmware for unity, or change R2 in the output stage to 39 k.
2. **Codec full scale / abs max reached before op-amp clipping.** The Seed3 codec's ±1.8 V is both its 0 dBFS swing (Table 3) and its absolute-maximum rating (Table 1). The codec pin reaches it at ≈3.7 V pk at the jack; the op-amps stay clean to ≈4.4 V pk. So the pedal's input ceiling is ≈3.7 V pk (fine for passive guitar, marginal for hot active bass) and, past it, the op-amps can drive the codec beyond its rating. Decision: **fit BAT54S Schottky clamps** (to AGND / +3V3A) at each codec input on the carrier board — they protect the codec, they do not add headroom (§3 rule 2 resolved). More headroom would need a lower second-stage gain plus a matching output-trim change.
3. **Fuzz CPU.** 4× oversampled ADAA fuzz with 128-tap FIRs costs 1.6 % of real time on an M4 Pro; the other three effects together < 0.3 %. Extrapolated to the M7 this is the block most likely to exceed the §5 budget — measure first on hardware, fall back to 2× (`Oversample` param) if `CpuLoadMeter` max > 75 %.
4. **Emulator fidelity vs SPICE** (behavioral OPA1652 substitute): input stage 0.39 dB / 4.9° (phase passes marginally, in the 20 kHz band edge where the sweep is fading), output 0.32 dB / 1.6°, identical clip onset, THD tracking within 0.1 % absolute. Passes §12. Re-run against the TI macromodel when downloaded, and against the real board in Phase B.
5. Anti-aliasing measured: hard-clip fuzz non-harmonic energy −28 dB (1×, ADAA only) → −42 dB (4× + ADAA).

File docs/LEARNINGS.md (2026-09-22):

# Learnings

Non-obvious things this project cost time to find. Each one is a real bug or fact that was
caught by a check, not by reasoning — which is the argument for keeping the checks.

## Circuit / DSP

**The input-stage gain was wrong by 1.6 dB, and only SPICE caught it.** The hand-derived
model said the 3k3/4k7 divider gives 0.5875. It does not: the second stage's 10 kΩ input
resistor loads the 4k7 leg, so it is 3k3/(4k7‖10k) = 0.492 (−6.2 dB). Found by comparing the
emulator's simple model against an ngspice run of the same schematic.

**The codec's ±1.8 V is both 0 dBFS and the absolute-maximum rating.** So "add clamp diodes for
headroom" was wrong twice over: clamps do not add headroom, and the codec node sits at the 4.5 V
AREF bias, so diodes to GND/+3V3 would clamp at the wrong levels anyway. The fix was gain
structure — second stage 6k8/10k = 0.68, so the op-amp hits its rails (±4.4 V × 0.492 × 0.68 =
1.48 V) before the codec sees its limit.

**Three of the four coupling capacitors per channel were drawn backwards.** Polarised
electrolytics must face the node with the higher DC level; checking each cap against the DC
level on both sides is a distinct review pass from checking connectivity.

**Bypass with trails was attenuating the dry signal.** A bypassed delay/reverb still ran its
`(1 − mix)` dry gain while the tail decayed, so bypassing ducked the dry path; with feedback > 1
the tail never decayed, making it permanent. Dry now passes at unity when bypassed, and
feedback/decay are capped below 1 while bypassed. This would have shipped into the pedal
firmware too — the emulator caught it.

**Oversampler latency is not (taps−1)/2 per stage.** For a matched up/down pair the impulse
lands at exactly `kTapsPerPhase − 1` input samples; derive it by measuring the impulse, not by
algebra on the FIR length.

**4× oversampling + ADAA moved the fuzz's non-harmonic energy from −28 dB to −42 dB.** Worth the
CPU: the fuzz costs ~1.6 % of real time on an M4 Pro versus <0.3 % for the other three effects
combined, and is the block most at risk on the Cortex-M7.

## Toolchain and platform

**A JUCE standalone that "crashes" on macOS may be missing `NSMicrophoneUsageDescription`.**
macOS kills any app that opens the audio input without it. It survives when launched from a
terminal (inherits that terminal's permission) and dies when launched from Finder — which looks
exactly like an intermittent crash.

**"It crashed" was a hang.** A 30 Hz full-window `repaint()` on a Retina display burned 88 % CPU
and starved the UI thread. Check whether the process is still alive before debugging a crash:
still running = hang, and the absence of a report in `~/Library/Logs/DiagnosticReports` is
evidence, not an accident.

**ASan hangs at startup on macOS 26.** Its shadow-memory init never returns. Use lldb plus an
in-process stress harness instead (`emulator/juce/Harness.cpp`).

**pluginval forks a child process by default**, so a shell wrapper reads an empty exit code and
reports failure on a passing plugin. Use `--validate-in-process` and read the exit code from
`Start-Process -PassThru`.

**Windows packaging (the defect Roman hit).** A JUCE plugin built with the default `/MD` runtime
imports `MSVCP140.dll` / `VCRUNTIME140*.dll` and will not load on a machine without the Visual
C++ 2015-2022 Redistributable — the DAW reports only "import failed". Build with
`CMAKE_MSVC_RUNTIME_LIBRARY=MultiThreaded` and enforce it (`tools/check_pe_imports.py`, pure
stdlib PE parser, runs on any OS). Related: a VST3 is a *folder* bundle; dragging it into a DAW
never installs anything, and dragging out of Windows' zip preview copies an incomplete folder.
Ship an installer.

**MSVC leaves struct padding uninitialised**, so a byte-for-byte `memcmp` of a preset struct
fails on Windows while passing on clang. Compare fields.

## KiCad

**KiCad 10 library files are deeply nested s-expressions.** Regex extraction of pins/symbols
silently returns nothing or the wrong block; write a real parser (`hardware/kicad/tools/sexp.py`).

**Local labels get a sheet-path prefix (`/GND`) in the exported netlist**, which fails
`--schematic-parity` against the board's `GND`. Use global labels in a generated flat schematic.

**Generate the schematic and the PCB from one netlist description**, then gate on
`kicad-cli sch export netlist` matching that description pad-for-pad (`tools/check_netlist.py`).
That check is what makes a script-generated board trustworthy.

**Electro-Smith publishes an official KiCad symbol/footprint** (DaisyKiCad) and the Seed3 STEP
model in a separate `Seed3-models.zip`. Several stock KiCad footprints have **no** 3D model
anywhere upstream — Neutrik NMJ6HCD2, Alpha RD901F, Fuse_1812 — so an empty render is expected,
not a broken install.

**KiCadRoutingTools rules worth obeying:** never copy a `.kicad_pcb` without its sibling
`.kicad_pro` (it carries the DRC floor), route to a fresh output path each run, and grade with
both `check_drc.py` *and* `check_connected.py` — a DRC-clean board can be entirely disconnected.

## Agent-safety plumbing

**A text-pattern guard on Bash produces false positives that block real work.** Heredoc bodies
and quoted multi-line commit messages were parsed as command words; `git remote -v` and
`git config --get` are read-only but matched a mutation rule. Each was found by the guard
blocking a legitimate action — hence `.claude/hooks/test_guard.py` (64 allow/deny cases) so the
rules can be changed without re-breaking the last fix.

**The guard is enforcement; the prompt is policy.** Instructions telling a model to ignore
injected email are only as good as the model's compliance. A `PreToolUse` hook that inspects the
actual tool arguments — recipient, body, path, command — is what makes "it cannot read outside
the repo" a statement about the system rather than about intentions.

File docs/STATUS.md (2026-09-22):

# Project status — 2026-09-22

Snapshot for picking this up in a new session. Honest about what is proven and what is not.

## Where things stand

| Area | State |
|---|---|
| DSP core (`firmware/dsp`) | **Done, tested.** Tremolo (incl. harmonic), 2 s stereo delay, Dattorro plate reverb, oversampled ADAA fuzz, reorderable chain with trails, global HP/LP, tap tempo, presets, MIDI map. 46 property tests pass. |
| Emulator CLI (`emulator/cli`) | **Done.** `emu` renders WAV through the pedal, optional analog+codec model, per-effect CPU cost. |
| Emulator GUI (JUCE) | **Builds and runs** on macOS and Windows: Standalone + VST3. Loop player (3 built-in CC0 loops + load a file), on-screen keyboard sampler, BPM entry, soft-takeover knobs. |
| SPICE validation (`hardware/spice`) | **Done, passing.** ngspice reference vs the emulator's analog model: 0.39 dB / 4.9° (input), 0.32 dB / 1.6° (output), matching clip onset. |
| KiCad board (`hardware/kicad`) | **Generated and routed.** 150 × 102 mm 2-layer, 111 footprints, 77 nets, all routed, **0 DRC errors** with schematic parity. Exports in `hardware/kicad/out/` (STEP, gerbers+drill, BOM, PDF, renders). |
| Daisy firmware (`firmware/daisy`) | **Written, never compiled** — no `arm-none-eabi-gcc` on this Mac. Expect libDaisy API-name fixes. |
| ESP32 firmware (`firmware/esp32`) | **Written, never compiled** — no PlatformIO/ESP-IDF here. |
| Web UI (`web/index.html`) | Written, never run against a real ESP32 bridge. |
| CI + releases | **Working.** GitHub Actions builds macOS + Windows on every push; a `v*` tag publishes a release. Latest: v0.1.3. |

## Verified vs unverified

Verified by something other than my say-so:
- 46 DSP property tests (delay lands the impulse at exactly N samples, RT60 grows with decay, 14-bit CC, preset round-trip, aliasing floor, …).
- `PedalHarness` drives the real processor + editor with concurrent audio at 44.1/48/96 kHz.
- SPICE-vs-model comparison report (`hardware/spice/validate/out/report.md`).
- KiCad ERC 0 violations; netlist parity gate (`tools/check_netlist.py`); `kicad-cli pcb drc --schematic-parity` 0 errors.
- Windows VST3: pluginval strictness 8 SUCCESS, standalone launched and screenshotted on the runner, published zip re-extracted and re-validated, no dynamic MSVC-runtime dependency.

**Not** verified:
- The plugin has never been loaded in a DAW by hand (Roman is testing; see below).
- No firmware has been compiled or run on hardware.
- No PCB has been fabricated; enclosure fit, ESP32-C3 SuperMini row spacing (placed at 15.24 mm) and the jack/pot mechanical fit are all unconfirmed.
- The emulator's analog model is validated against *SPICE*, not against a real board.

## Immediate next steps

1. **Roman's Windows test.** v0.1.3 fixed a real defect (see `docs/LEARNINGS.md`, "Windows packaging"). Ask him: which DAW and is it 64-bit; does the installer route work. No email has been sent about v0.1.3.
2. **Hardware Phase A** (`docs/design.md` §11): breadboard the Seed3 with the datasheet instrument I/O, measure noise floor, latency, current draw, and `CpuLoadMeter` per effect. The fuzz at 4× oversampling is the block most likely to blow the CPU budget — fall back to 2× if max load > 75 %.
3. **Toolchains** to install before firmware can be built: `arm-none-eabi-gcc` + libDaisy, PlatformIO (ESP32), `dfu-util`.
4. **Board review** before ordering: ESP32 row spacing, 5-footswitch pitch vs enclosure (1590XX at ~29 mm is too tight — 4+1 rows or 1590DD), and the Seed3 3D model is not attached to U1.

## Resuming work

```sh
cd emulator && cmake -B build -DPEDAL_BUILD_JUCE=ON && cmake --build build -j8   # CLI + tests + GUI
./build/dsp_tests                                                                 # 46 property tests
cmake -B build -DPEDAL_HARNESS=ON && ./build/juce/PedalHarness_artefacts/Release/PedalHarness
cd ../hardware/spice/validate && python3 run_all.py                               # SPICE comparison
cd ../../kicad && python3 tools/gen_sch.py && ./route.sh                          # regenerate + route the board
/usr/bin/python3 .claude/hooks/test_guard.py                                      # 64 guard cases
```

## Session-specific things that did **not** survive

- A 10-minute cron loop that watched Gmail for bug reports from Roman (deleted on request; it only ever found no mail, and sent nothing).
- Nothing else — everything of value is committed.

## The repo guard is active and persists

`.claude/settings.json` + `.claude/hooks/guard.py` confine any Claude Code session in this repo:
file tools to the repo and scratchpad, Bash to a build/test/git/gh allowlist, Gmail to in-thread
replies with a secret scan, and other connectors/web off. It is enforced by the harness, not by
good intentions. **It will block work outside this repo** — including writing to Claude's own
memory directory. Relax or remove `.claude/settings.json` if that gets in the way.

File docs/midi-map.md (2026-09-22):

# Control protocol (MIDI)

One protocol for every control path: physical controls on the Daisy, BLE-MIDI,
the web UI (JSON ⇄ MIDI on the ESP32) and the emulator's MIDI input all speak this map.
Defined in `firmware/dsp/include/pedal/midi.h`; the web UI's JSON form is in `firmware/esp32/src/main.cpp`.

Effects: 0 Tremolo, 1 Delay, 2 Reverb, 3 Fuzz. Parameters are normalised 0..1; the
real-unit curves are in each effect's `paramDesc()` (and mirrored in `web/index.html`).

| message | meaning |
|---|---|
| CC 0–31 (MSB), CC 32–63 (LSB) | effect `cc/8`, parameter `cc%8`; 14-bit when the LSB follows |
| CC 64–67 | enable effect 0–3 (≥64 = on) |
| CC 70 / 71 | global high-cut / low-cut toggle position 0 off, 1 slot A, 2 slot B |
| CC 72 | tap tempo (each message = one tap) |
| CC 74 / 75 | input / output trim, −12…+12 dB |
| PC n | load preset n (0–7) |
| SysEx `F0 7D 01 o0 o1 o2 o3 F7` | chain order (effect ids in signal order) |
| SysEx `F0 7D 02 n F7` / `03 n` | save / load preset n |
| SysEx `F0 7D 04 s hi lo F7` | high-cut slot s (0/1) corner frequency, 14-bit Hz |
| SysEx `F0 7D 05 s hi lo F7` | low-cut slot s corner frequency |
| SysEx `F0 7D 06 hi lo F7` | tempo, 14-bit ms per beat |
| SysEx `F0 7D 07 F7` | request full state → device answers with a dump (all of the above) |
| SysEx `F0 7D 20 F7` | Daisy → ESP32: start the WiFi AP (TAP held 3 s) |

Parameter index per effect (CC = effect×8 + index):

| | 0 | 1 | 2 | 3 | 4 | 5 | 6 | 7 |
|---|---|---|---|---|---|---|---|---|
| Tremolo | Rate | Depth | Shape | Harmonic | StereoPhase | Crossover | Volume | – |
| Delay | Time | Feedback | Mix | LowCut | HighCut | Mod | PingPong | Subdiv |
| Reverb | Mix | Decay | PreDelay | HighCut | LowCut | Mod | Diffusion | Width |
| Fuzz | Gain | Bias | Tone | Volume | Mode | Oversample | Gate | LowCut |

Footswitch gestures (Daisy and emulator): press = toggle effect / tap; hold TAP 0.5 s then
press an effect switch = bind the knob bank to that effect; hold fx1 + fx4 2 s = DFU;
hold TAP 3 s = start WiFi AP.

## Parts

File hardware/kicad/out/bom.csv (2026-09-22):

Reference | Value | Footprint | MPN | Description
C101,C104,C201,C204,C301,C303,C401,C403 | 10u/50V | Capacitor_THT:CP_Radial_D5.0mm_P2.00mm |  | in L coupling,in L stage-2 coupling,in R coupling,in R stage-2 coupling,out L DAC coupling,out L coupling,out R DAC coupling,out R coupling
C102,C202,C302,C402 | 100p | Capacitor_SMD:C_0805_2012Metric |  | in L rf,in R rf,out L fb,out R fb
C103,C203 | 1n | Capacitor_SMD:C_0805_2012Metric |  | in L divider lp,in R divider lp
C105,C205 | 470p | Capacitor_SMD:C_0805_2012Metric |  | in L stage-2 fb (~50 kHz),in R stage-2 fb (~50 kHz)
C106,C206 | 33n | Capacitor_SMD:C_0805_2012Metric |  | in L codec lp,in R codec lp
C501-C505 | 100u/16V | Capacitor_THT:CP_Radial_D6.3mm_P2.50mm |  | rail bulk
C506,C511,C512,C514,C521-C524 | 100n | Capacitor_SMD:C_0805_2012Metric |  | +5V_ESP hf,+5V_SEED hf,+9V hf,AREF out hf,U2 decoupling,U3 decoupling,U4 decoupling,U6 decoupling
C507 | 10u/25V | Capacitor_SMD:C_0805_2012Metric |  | buck Cin
C508,C509 | 22u/10V | Capacitor_SMD:C_0805_2012Metric |  | buck Cout
C510 | 100n | Capacitor_SMD:C_0603_1608Metric |  | buck BST
C513 | 10u | Capacitor_SMD:C_0805_2012Metric |  | AREF divider filter
D1 | NSR1020MW2 | Diode_SMD:D_SOD-323 | onsemi NSR1020MW2T3G | reverse polarity, SOD-323
D2 | SMAJ12A | Diode_SMD:D_SMA | Littelfuse SMAJ12A | surge clamp
D21 | LED Tremolo | LED_THT:LED_D3.0mm |  | 3 mm
D22 | LED Delay | LED_THT:LED_D3.0mm |  | 3 mm
D23 | LED Reverb | LED_THT:LED_D3.0mm |  | 3 mm
D24 | LED Fuzz | LED_THT:LED_D3.0mm |  | 3 mm
D25 | LED Tempo | LED_THT:LED_D3.0mm |  | 3 mm
F1 | 1A PTC | Fuse:Fuse_1812_4532Metric | Bourns MF-MSMF110-2 | resettable fuse
FB1-FB4 | 220R@100MHz | Inductor_SMD:L_0805_2012Metric | Murata BLM21PG221SN1D | ESP32 5V bead,Seed 5V bead,analog rail bead,input bead
J1 | DC 9V centre-neg | Connector_BarrelJack:BarrelJack_Horizontal | CUI PJ-102AH or Lumberg 1613 09 | 2.1 mm barrel; pedal standard: sleeve = +9 V, centre = 0 V
J2 | IN TRS | Connector_Audio:Jack_6.35mm_Neutrik_NMJ6HCD2_Horizontal | Neutrik NMJ6HCD2 | input, TS = mono
J3 | OUT TRS | Connector_Audio:Jack_6.35mm_Neutrik_NMJ6HCD2_Horizontal | Neutrik NMJ6HCD2 | output
J5 | ESP32-C3 SuperMini A | Connector_PinSocket_2.54mm:PinSocket_1x08_P2.54mm_Vertical |  | left row: 5V GND 3V3 IO0 IO1 IO2 IO3 IO4
J6 | ESP32-C3 SuperMini B | Connector_PinSocket_2.54mm:PinSocket_1x08_P2.54mm_Vertical |  | right row: IO5 IO6 IO7 IO8 IO9 IO10 IO21 IO20
J11 | FS Tremolo | Connector_JST:JST_XH_B2B-XH-A_1x02_P2.50mm_Vertical | JST B2B-XH-A | to SPST momentary footswitch
J12 | FS Delay | Connector_JST:JST_XH_B2B-XH-A_1x02_P2.50mm_Vertical | JST B2B-XH-A | to SPST momentary footswitch
J13 | FS Reverb | Connector_JST:JST_XH_B2B-XH-A_1x02_P2.50mm_Vertical | JST B2B-XH-A | to SPST momentary footswitch
J14 | FS Fuzz | Connector_JST:JST_XH_B2B-XH-A_1x02_P2.50mm_Vertical | JST B2B-XH-A | to SPST momentary footswitch
J15 | FS TAP | Connector_JST:JST_XH_B2B-XH-A_1x02_P2.50mm_Vertical | JST B2B-XH-A | to SPST momentary footswitch
L1 | 4u7 | Inductor_SMD:L_Bourns_SRN6045TA | Bourns SRN6045TA-4R7M | buck inductor
R61-R65 | 1k | Resistor_SMD:R_0805_2012Metric |  | LED Delay series,LED Fuzz series,LED Reverb series,LED Tempo series,LED Tremolo series
R101,R201 | 1M | Resistor_SMD:R_0805_2012Metric |  | in L bias,in R bias
R102,R106,R202,R206,R304,R404,R504,R505 | 10k | Resistor_SMD:R_0805_2012Metric |  | AREF divider,in L stage-2 in,in L tip-normal pull-down,in R stage-2 in,in R tip-normal pull-down,out L load,out R load
R103,R108,R203,R208,R303,R403 | 100R | Resistor_SMD:R_0805_2012Metric |  | in L codec series,in L rf,in R codec series,in R rf,out L series,out R series
R104,R204 | 3k3 | Resistor_SMD:R_0805_2012Metric |  | in L divider,in R divider
R105,R205 | 4k7 | Resistor_SMD:R_0805_2012Metric |  | in L divider,in R divider
R107,R207 | 6k8 | Resistor_SMD:R_0805_2012Metric |  | in L stage-2 fb (gain 0.68: codec never exceeds 1.8 V),in R stage-2 fb (gain 0.68: codec never exceeds 1.8 V)
R301,R401 | 15k | Resistor_SMD:R_0805_2012Metric |  | out L in,out R in
R302,R402 | 33k | Resistor_SMD:R_0805_2012Metric |  | out L fb,out R fb
R501-R503 | 3R3 | Resistor_SMD:R_1206_3216Metric |  | rail RC filter
RV1-RV6 | B10k | Potentiometer_THT:Potentiometer_Alpha_RD901F-40-00D_Single_Vertical | Alpha RD901F-40-15F-B10K | knob 1,knob 2,knob 3,knob 4,knob 5,knob 6
SW1 | HP cut ON-OFF-ON | pedal:SW_Toggle_2M_SPDT_Vertical | Dailywell 2MS3T1B1M2QES | global high-cut toggle
SW2 | LP cut ON-OFF-ON | pedal:SW_Toggle_2M_SPDT_Vertical | Dailywell 2MS3T1B1M2QES | global low-cut toggle
U1 | Daisy Seed3 | Daisy-Boards:DAISY_SEED | Electro-Smith Seed3 | DSP board, socketed (2x 1x20 female headers)
U2-U4,U6 | OPA1652AIDR | Package_SO:SOIC-8_3.9x4.9mm_P1.27mm | TI OPA1652AIDR | A output L, B AREF buffer,A output R, B spare follower,input L: A buffer, B inverting,input R: A buffer, B inverting
U5 | AP63205WU-7 | Package_TO_SOT_SMD:TSOT-23-6 | Diodes AP63205WU-7 | 9V->5V buck 2A

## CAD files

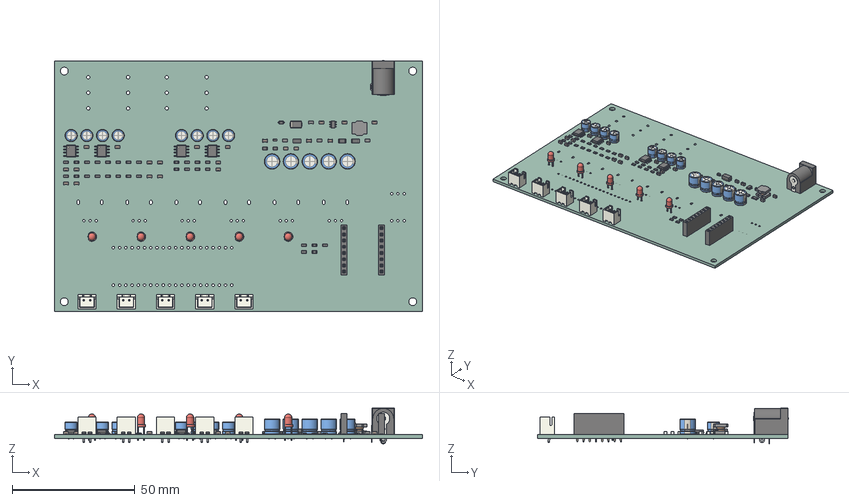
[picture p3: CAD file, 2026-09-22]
hardware/kicad/out/pedal.step
150.0 x 102.3 x 14.6 mm
R_0805_2012Metric x 31
LED_D3.0mm x 5
CP_Radial_D63mm_P250mm x 5
C_0805_2012Metric x 22
SOIC-8_3.9x4.9mm_P1.27mm x 4
TSOT-23-6
CP_Radial_D50mm_P200mm x 8
JST_B2B_XH_A x 5
L_0805_2012Metric x 4
R_1206_3216Metric x 3
D_SMA
PinSocket_1x08_P2.54mm_Vertical x 2
D_SOD-323
C_0603_1608Metric
L_Bourns_SRN6045TA
BarrelJack_Horizontal
pedal_PCB

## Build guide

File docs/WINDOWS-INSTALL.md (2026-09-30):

# PedalEmu on Windows

## Easiest: run the installer

Download `PedalEmu-<version>-windows-x64-setup.exe` from the release page and run it.
It puts the VST3 in the shared VST3 folder and can optionally install the standalone app.
Windows SmartScreen may warn once because the installer is not code-signed: click
"More info" then "Run anyway".

After it finishes, rescan plug-ins in your DAW:

- Reaper: Options > Preferences > Plug-ins > VST > Re-scan (use "Clear cache/re-scan" if
  PedalEmu was installed before).
- Most other DAWs rescan on startup, or have a Rescan button in their plug-in settings.

PedalEmu then appears in the plug-in list as "PedalEmu" (VST3, guitar_pedal).

## Manual install from the zip

`PedalEmu.vst3` is a **bundle** - a folder, not a single file. Install it by copying:

1. Right-click the downloaded zip, choose Properties, tick **Unblock** if that box is
   there, then Extract All. Extract it first; do not drag files out of the zip preview
   window, which copies an incomplete folder.
2. Copy the whole `PedalEmu.vst3` **folder** into `C:\Program Files\Common Files\VST3\`.
3. Rescan plug-ins in your DAW as above.

**Dragging a .vst3 into a DAW window does not install a plugin** - most DAWs answer with
"import failed" or simply ignore it. Plugins are found by scanning the VST3 folder.

## If it still does not show up

- 64-bit DAW only; there is no 32-bit or ARM64 build.
- Check the file really is at
  `C:\Program Files\Common Files\VST3\PedalEmu.vst3\Contents\x86_64-win\PedalEmu.vst3`.
- Look at your DAW's plug-in scan log for the reason it rejected the file.
- Builds from v0.1.3 onward link the Visual C++ runtime statically, so no redistributable
  is needed. Earlier builds needed the "Visual C++ 2015-2022 Redistributable (x64)" and
  failed to load without it.

## Using it

The plugin starts on its built-in guitar loop, so you hear something with no input
connected. Pick *Live input* in the Source menu to run the track's audio through the
pedal, or play the on-screen keyboard (it also responds to MIDI sent to the track).
Every effect parameter is exposed for DAW automation, and the MIDI CC/SysEx map in
`docs/midi-map.md` works from a controller.

### Live guitar is silent (standalone app)

With *Live input* selected, the line under the Source menu shows the level on input 1
and input 2.

**Nothing on either input, and the input meter in Options > Audio Settings stays empty.**
The app is getting no audio from the interface at all. Setting the gain or the INST
switch will not change that. In Options > Audio Settings, set *Audio device type* to
**Windows Audio (Exclusive Mode)** and keep the sample rate at 48000 Hz. This fixed a
Volt 2 that delivered only silence in plain *Windows Audio* mode. Exclusive mode stops
other apps (a browser, say) from playing through the interface while PedalEmu is open.
Exclusive mode also allows small buffers. Try 128 samples and go up a step if you hear
crackles. From v0.1.5 the app flags this case under the Source menu after 3 s of
complete silence.

**Guitar on input 2 is silent with *TS plug (mono)* ticked.** If your guitar shows up on input 2 only (for example the second jack on a
Volt 2 or Scarlett), versions before v0.1.4 dropped it whenever *TS plug (mono)*
was ticked, because mono mode read input 1 alone. Mono mode now sums inputs 1 and 2.
On older builds, move the guitar to input 1 or untick *TS plug (mono)*.

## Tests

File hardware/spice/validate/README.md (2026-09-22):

# validate — simple analog model vs full ngspice reference

`python3 run_all.py` (needs `ngspice`, numpy/scipy/matplotlib, and `emulator/build/emu`):

1. `stimuli.py` writes the shared stimulus set as 48 kHz float WAV (volts) and as
   384 kHz PWL text for ngspice: 10 Hz–22 kHz log sweep at 0.1 V, 1 kHz level steps
   (50 mV → 8 V at the jack; 0.05 → 1.0 FS for the DAC), a band-limited 200 Hz square,
   and a synthetic plucked-string clip.
2. `run_models.py` runs `input_stage.cir` / `output_stage.cir` in ngspice (batch,
   `linearize`d to 192 kHz) and `emu --stage in|out` (the simple model, codec clamp
   disabled for the comparison).
3. `compare.py` decimates the SPICE output to 48 kHz, aligns the two, and reports:
   1/12-octave magnitude/phase error, THD and gain per level step, 1 dB compression
   onset, the input level at which the codec pin exceeds ±1.8 V, and normalised RMS
   waveform error. Output: `out/report.md`, `out/metrics.json`, PNG plots.

Pass criteria (docs/design.md §12): |mag| < 0.5 dB, |phase| < 5° over 20 Hz–20 kHz,
clip onset within 0.5 dB.

What the harness found so far (2026-09-21, behavioral op-amp model):
- The hand-derived input attenuation (0.5875) was wrong: the second stage's 10 kΩ input
  resistor loads the 4k7 leg → 0.492 (−6.2 dB). `AnalogParams::inAtten` was corrected.
- Both stages then pass: input 0.39 dB / 4.9°, output 0.32 dB / 1.6°, identical clip
  onset (5 V pk), THD vs level within 0.1 % absolute, NRMSE ≈ 2 % on program material.
- Design check: with the datasheet circuit the codec pin reaches ±1.8 V at ≈3.7 V pk
  at the jack while the op-amps stay clean to ≈4.4 V pk → add Schottky clamps at the
  codec input (or lower the second-stage gain) for active-pickup safety.

To use TI's OPA1652 model instead of the behavioral substitute, see `../models/README.md`.
Bench measurements of the real board go through the same `compare.py` path: record the
stimulus WAVs through the pedal and drop them in as a third "model".

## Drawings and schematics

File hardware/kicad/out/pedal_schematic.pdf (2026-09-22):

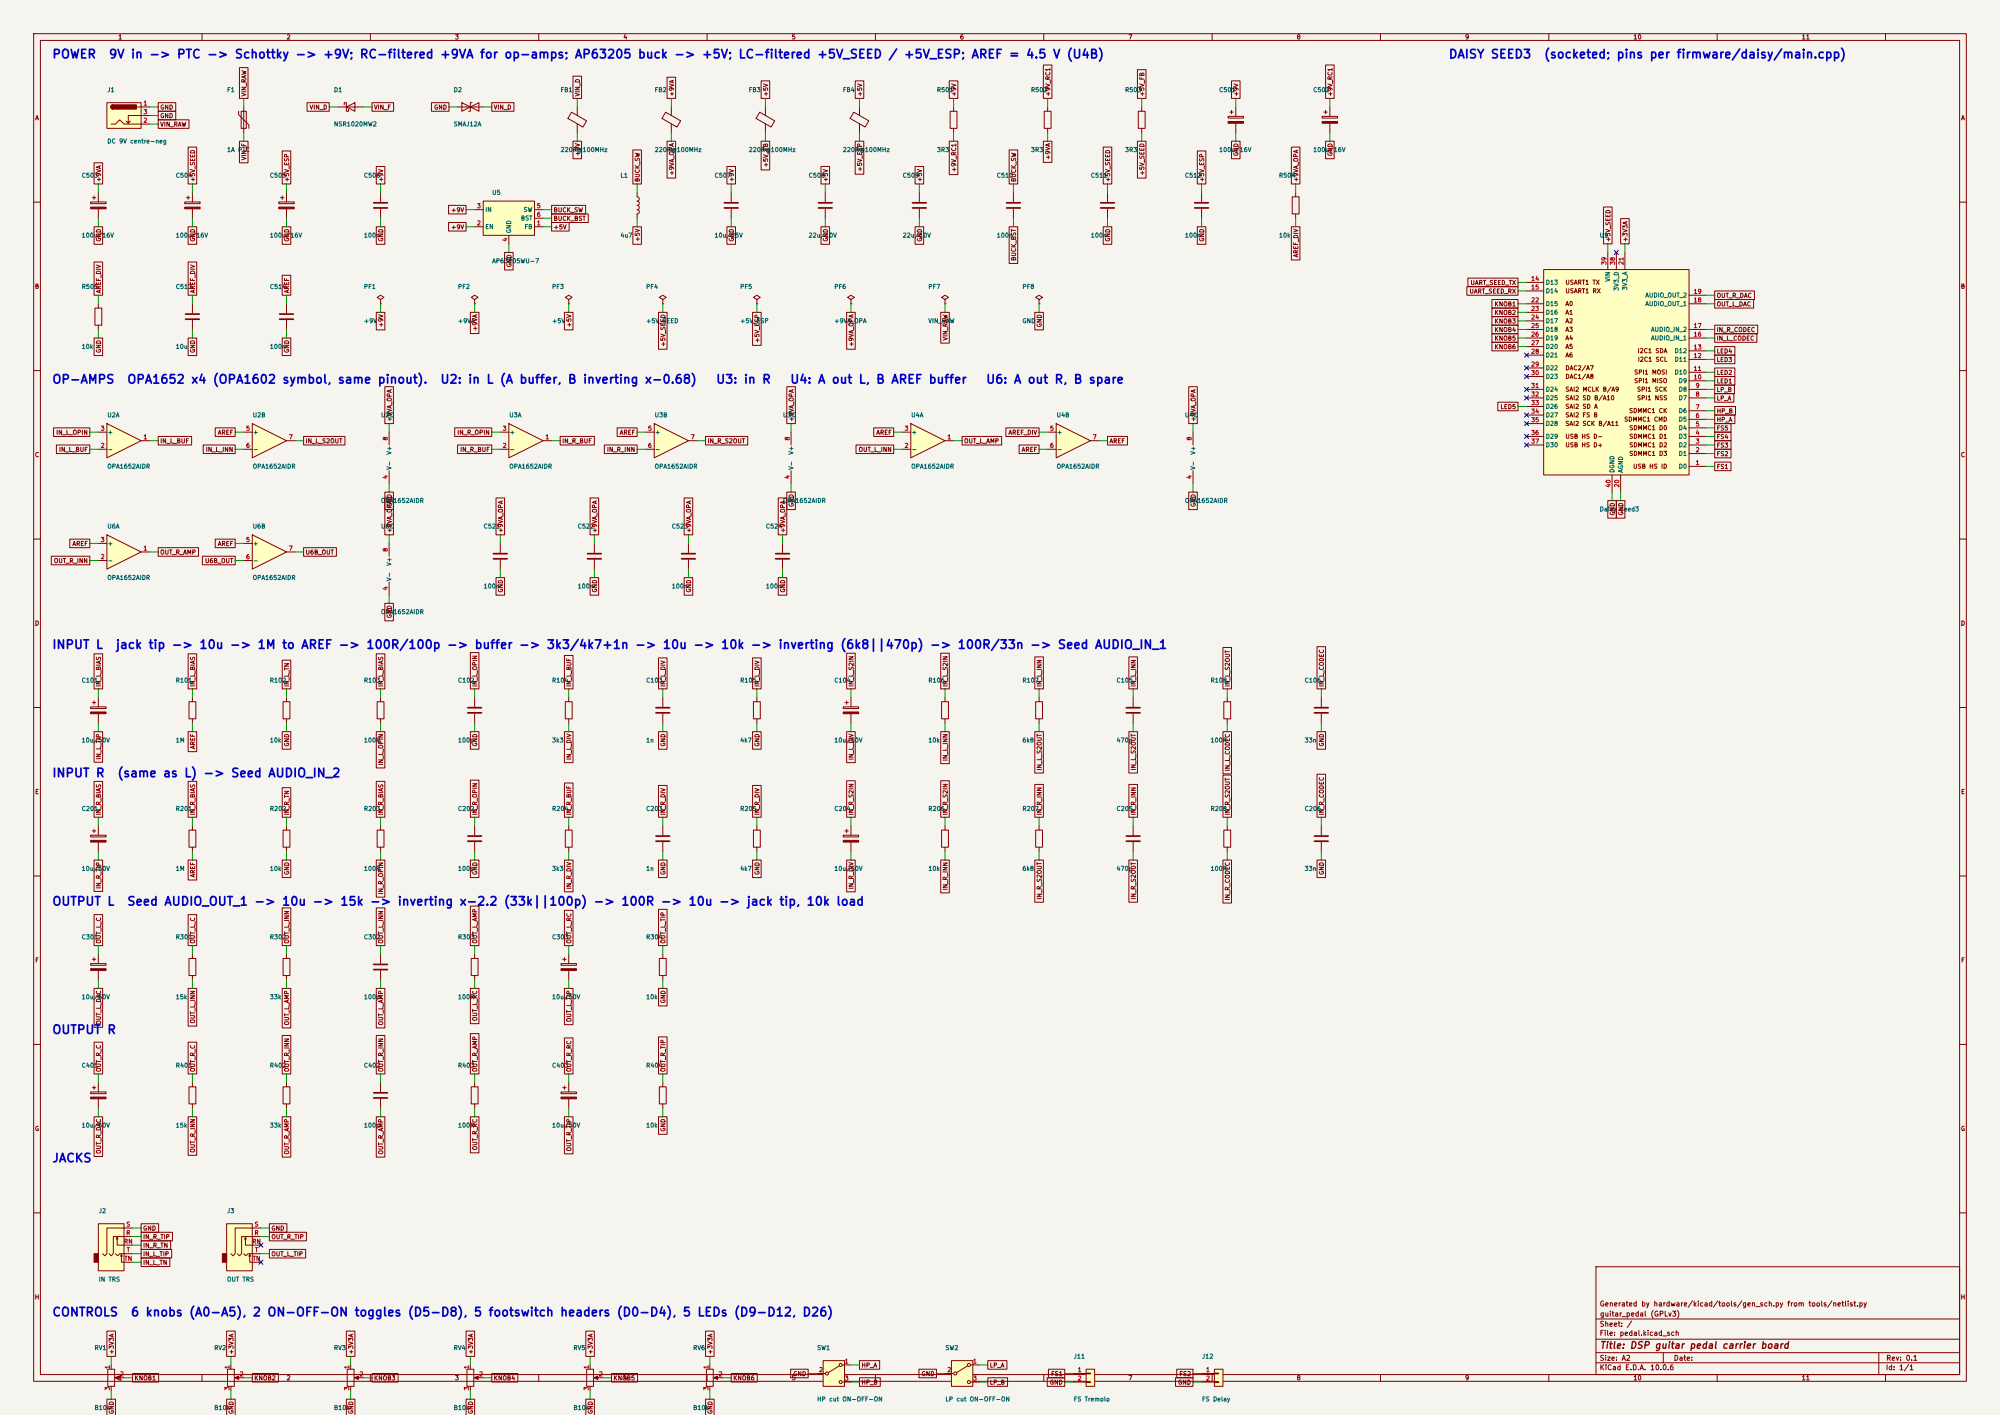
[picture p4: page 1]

POWER 9V in -> PTC -> Schottky -> +9V; RC-filtered +9VA for op-amps; AP63205 buck -> +5V; LC-filtered +5V_SEED / +5V_ESP; AREF = 4.5 V (U4B)

DAISY SEED3 (socketed; pins per firmware/daisy/main.cpp)

INPUT L jack tip -> 10u -> 1M to AREF -> 100R/100p -> buffer -> 3k3/4k7+1n -> 10u -> 10k -> inverting (6k8||470p) -> 100R/33n -> Seed AUDIO_IN_1

INPUT R (same as L) -> Seed AUDIO_IN_2

OUTPUT L Seed AUDIO_OUT_1 -> 10u -> 15k -> inverting x-2.2 (33k||100p) -> 100R -> 10u -> jack tip, 10k load

CONTROLS 6 knobs (A0-A5), 2 ON-OFF-ON toggles (D5-D8), 5 footswitch headers (D0-D4), 5 LEDs (D9-D12, D26)
FS Reverb 1

Generated by hardware/kicad/tools/gen_sch.py from tools/netlist.py
guitar_pedal (GPLv3)
Sheet: /
File: pedal.kicad_sch
Title: DSP guitar pedal carrier board

SW1 HP cut ON-OFF-ON

Size: A2 | Rev: 0.1
KiCad E.D.A. 10.0.6 | Id: 1/1

LP cut ON-OFF-ON

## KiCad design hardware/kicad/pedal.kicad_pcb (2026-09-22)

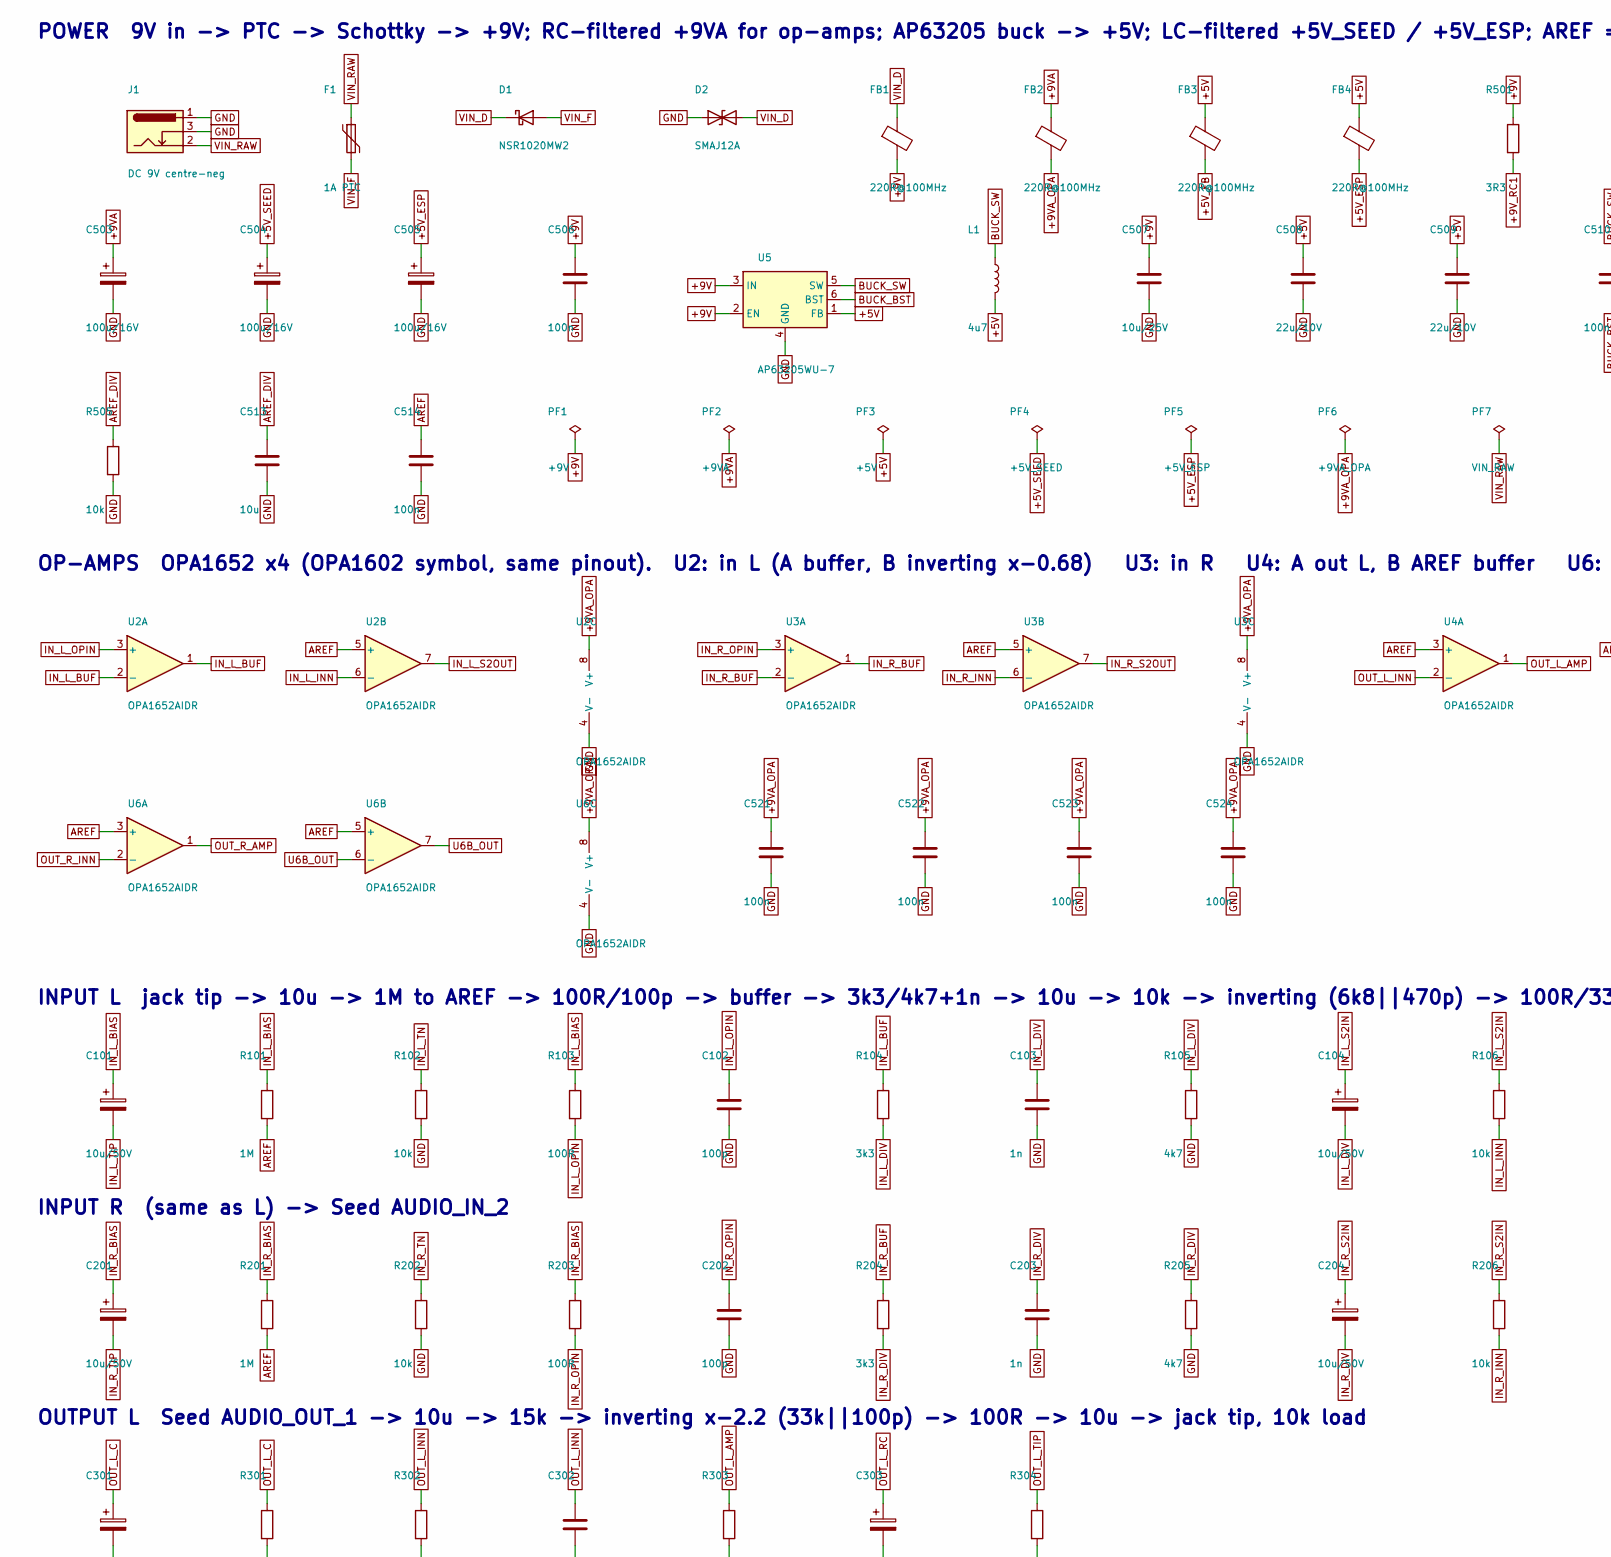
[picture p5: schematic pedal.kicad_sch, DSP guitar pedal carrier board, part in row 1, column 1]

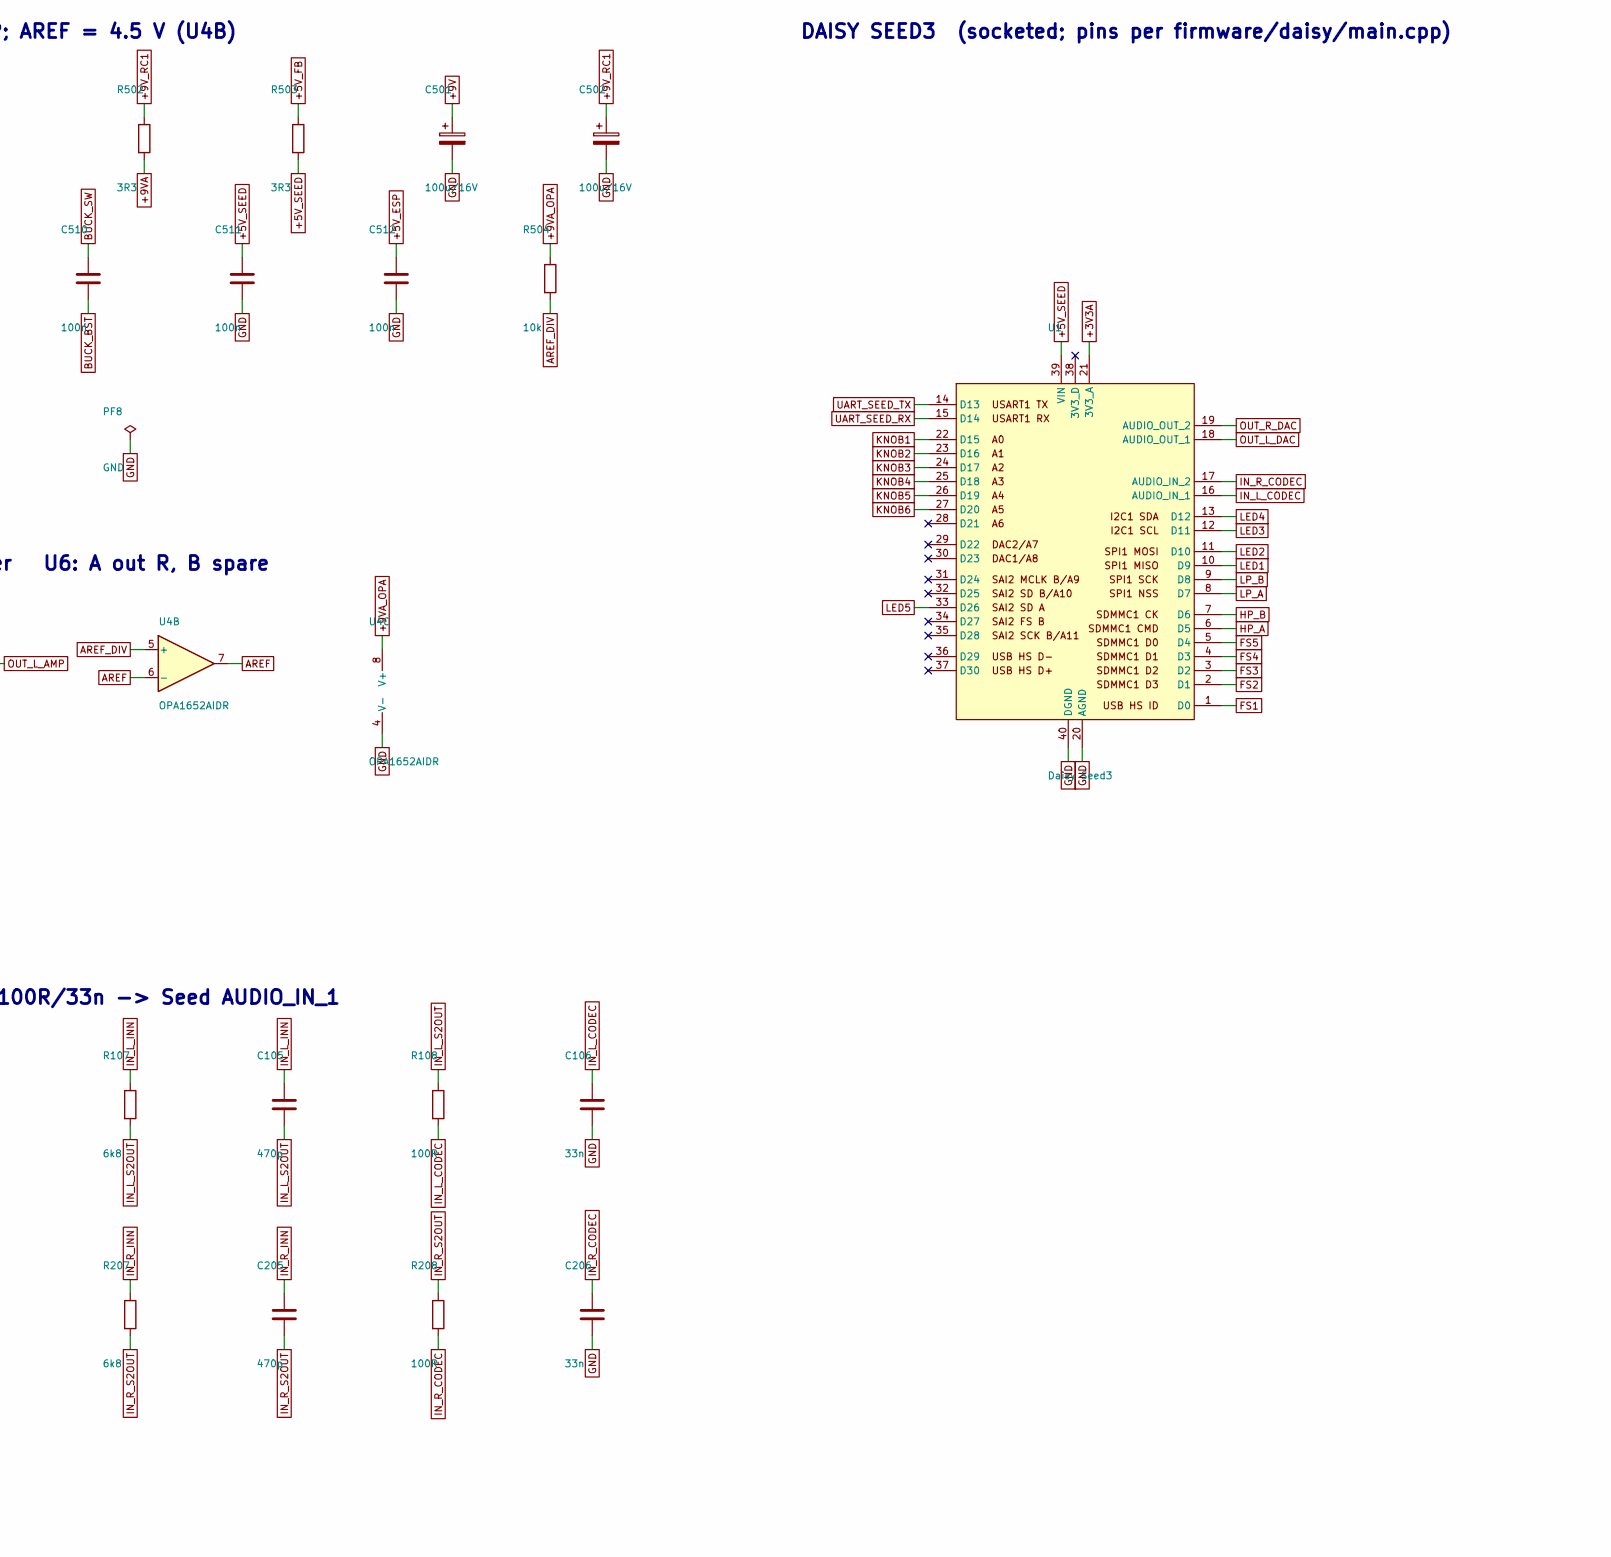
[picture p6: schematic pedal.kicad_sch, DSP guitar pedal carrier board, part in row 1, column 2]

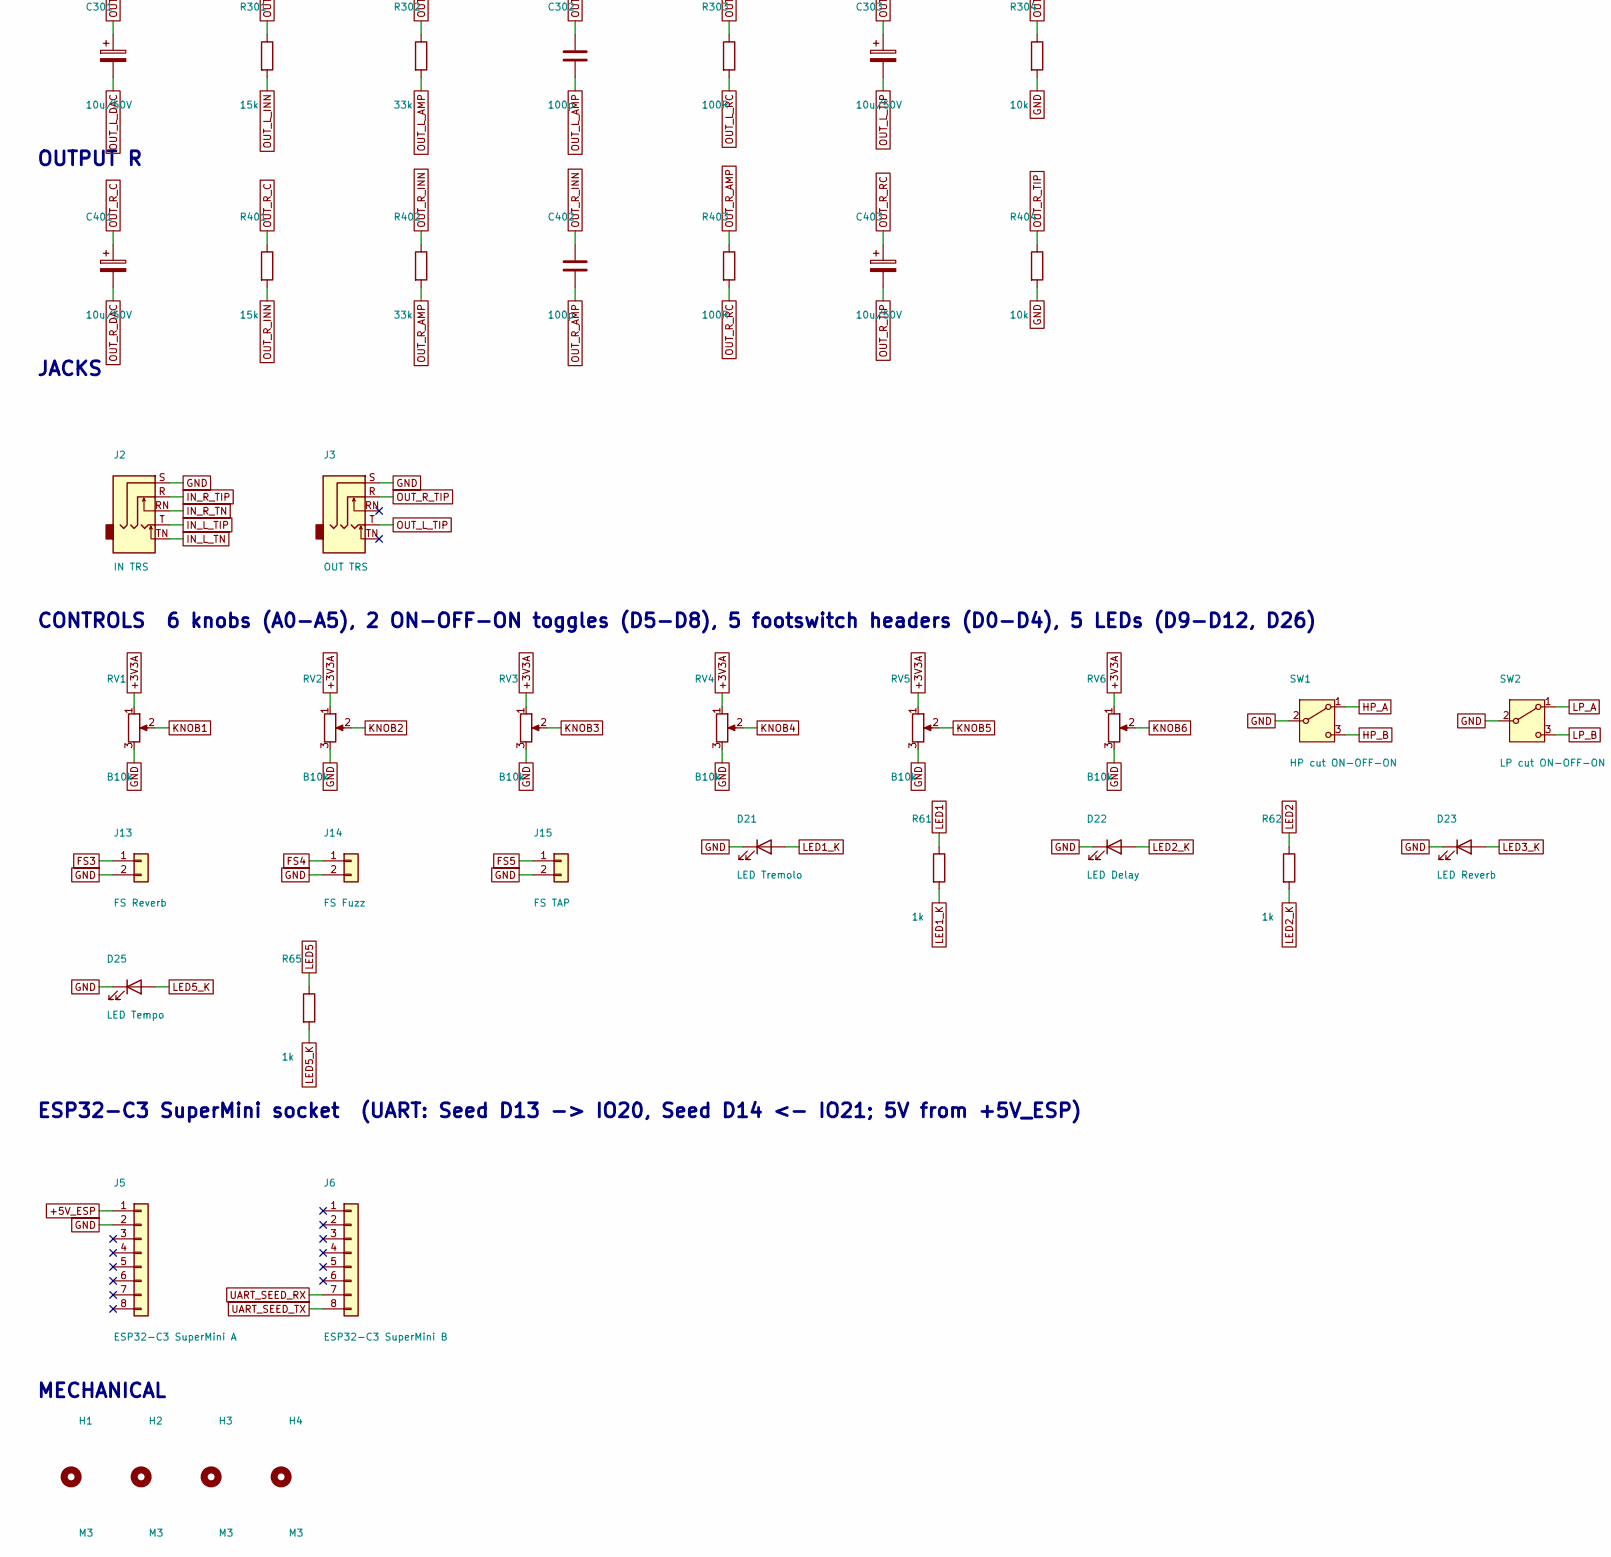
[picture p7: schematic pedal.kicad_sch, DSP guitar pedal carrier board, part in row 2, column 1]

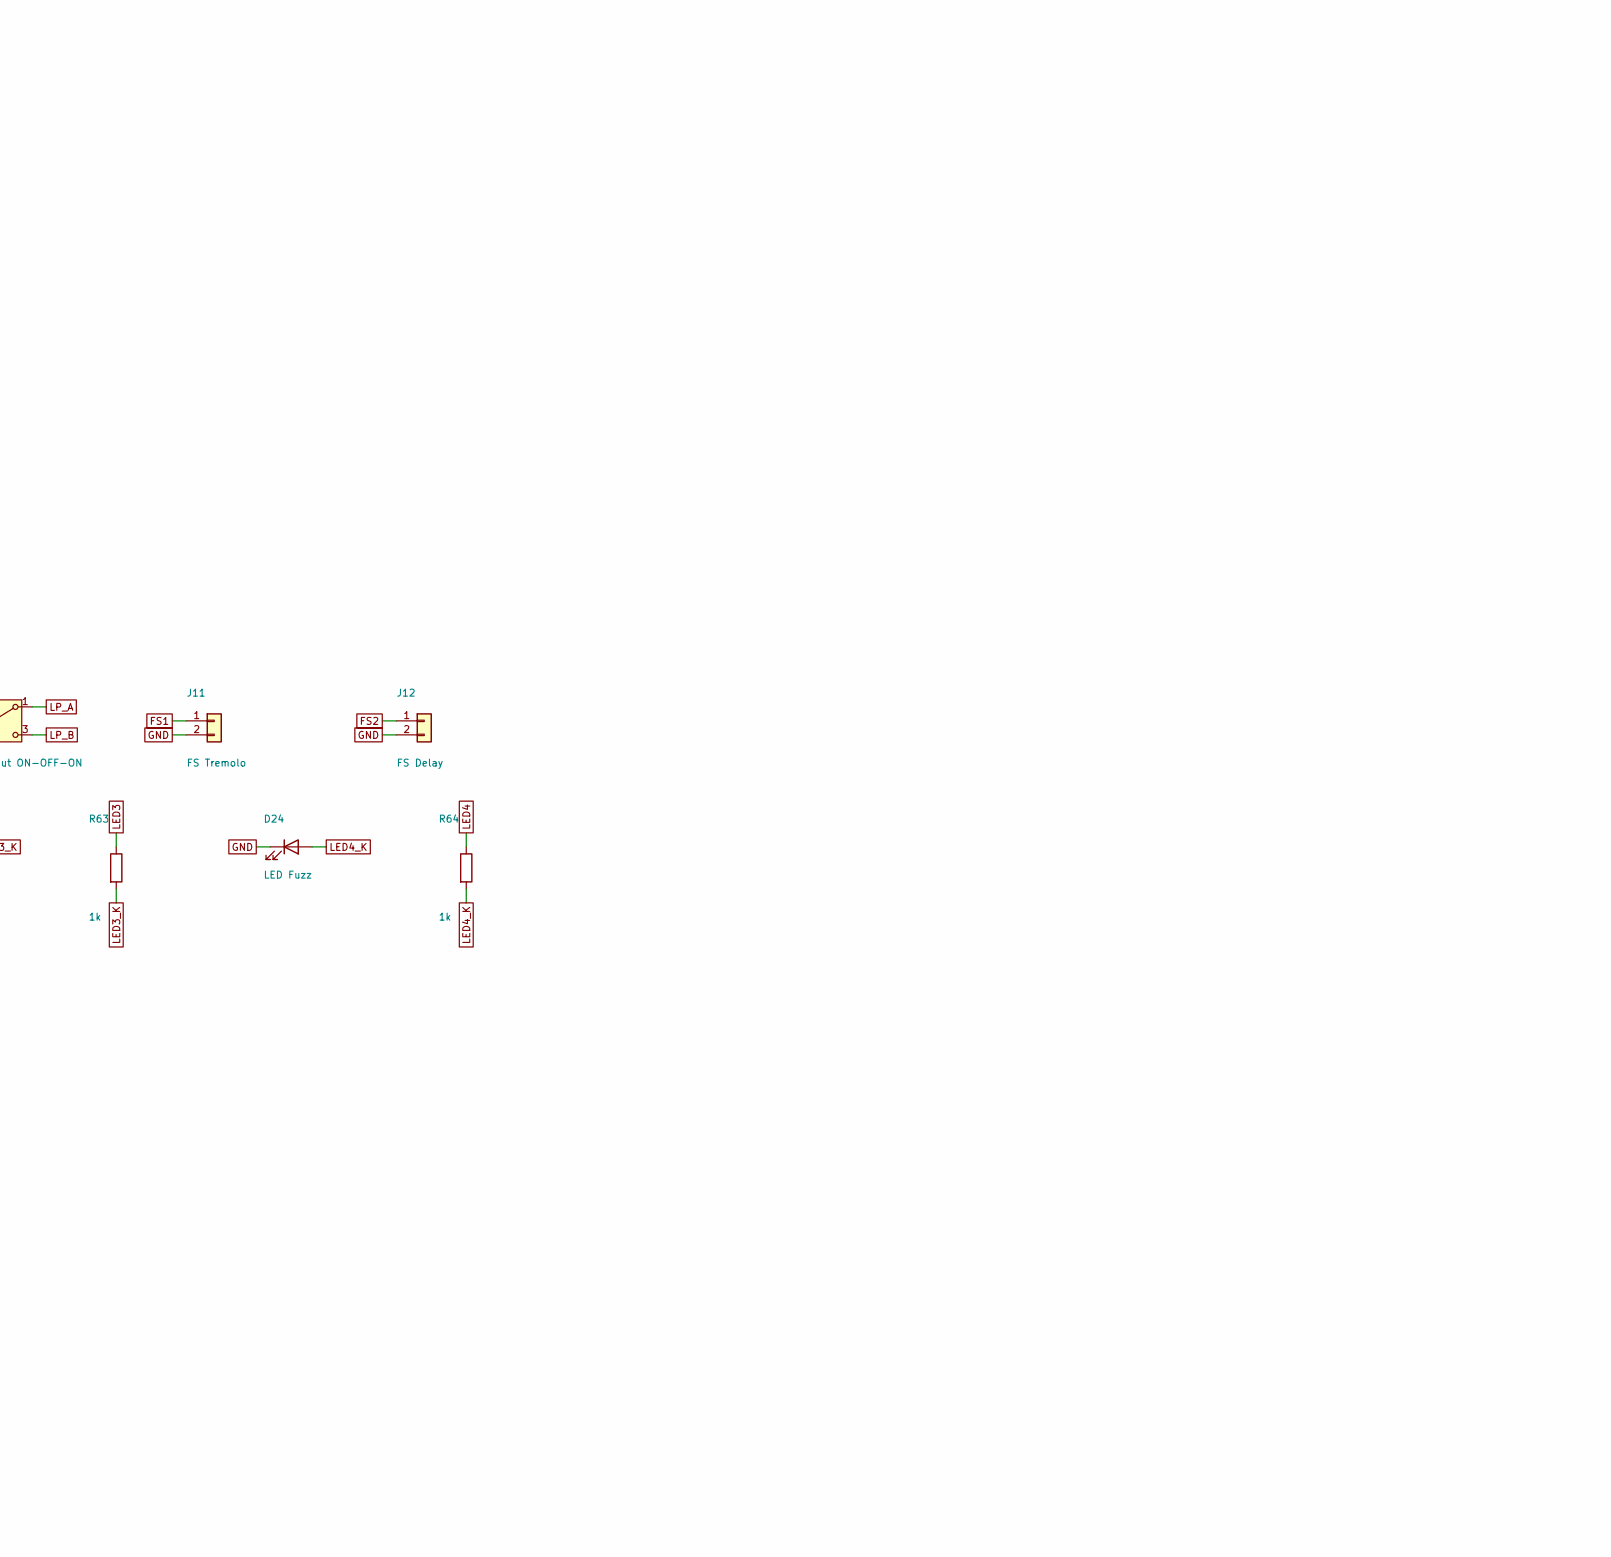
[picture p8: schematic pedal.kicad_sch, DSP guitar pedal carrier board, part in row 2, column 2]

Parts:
C101, C104, C201, C204, C301, C303, C401, C403: 10u/50V; CP_Radial_D5.0mm_P2.00mm
C102, C202, C302, C402: 100p; C_0805_2012Metric
C103, C203: 1n; C_0805_2012Metric
C105, C205: 470p; C_0805_2012Metric
C106, C206: 33n; C_0805_2012Metric
C501, C502, C503, C504, C505: 100u/16V; CP_Radial_D6.3mm_P2.50mm
C506, C511, C512, C514, C521, C522, C523, C524: 100n; C_0805_2012Metric
C507: 10u/25V; C_0805_2012Metric
C508, C509: 22u/10V; C_0805_2012Metric
C510: 100n; C_0603_1608Metric
C513: 10u; C_0805_2012Metric
D1: NSR1020MW2; D_SOD-323; MPN onsemi NSR1020MW2T3G
D2: SMAJ12A; D_SMA; MPN Littelfuse SMAJ12A
D21: LED Tremolo; LED_D3.0mm
D22: LED Delay; LED_D3.0mm
D23: LED Reverb; LED_D3.0mm
D24: LED Fuzz; LED_D3.0mm
D25: LED Tempo; LED_D3.0mm
F1: 1A PTC; Fuse_1812_4532Metric; MPN Bourns MF-MSMF110-2
FB1, FB2, FB3, FB4: 220R@100MHz; L_0805_2012Metric; MPN Murata BLM21PG221SN1D
H1, H2, H3, H4: M3; MountingHole_3.2mm_M3
J1: DC 9V centre-neg; BarrelJack_Horizontal; MPN CUI PJ-102AH or Lumberg 1613 09
J2: IN TRS; Jack_6.35mm_Neutrik_NMJ6HCD2_Horizontal; MPN Neutrik NMJ6HCD2
J3: OUT TRS; Jack_6.35mm_Neutrik_NMJ6HCD2_Horizontal; MPN Neutrik NMJ6HCD2
J5: ESP32-C3 SuperMini A; PinSocket_1x08_P2.54mm_Vertical
J6: ESP32-C3 SuperMini B; PinSocket_1x08_P2.54mm_Vertical
J11: FS Tremolo; JST_XH_B2B-XH-A_1x02_P2.50mm_Vertical; MPN JST B2B-XH-A
J12: FS Delay; JST_XH_B2B-XH-A_1x02_P2.50mm_Vertical; MPN JST B2B-XH-A
J13: FS Reverb; JST_XH_B2B-XH-A_1x02_P2.50mm_Vertical; MPN JST B2B-XH-A
J14: FS Fuzz; JST_XH_B2B-XH-A_1x02_P2.50mm_Vertical; MPN JST B2B-XH-A
J15: FS TAP; JST_XH_B2B-XH-A_1x02_P2.50mm_Vertical; MPN JST B2B-XH-A
L1: 4u7; L_Bourns_SRN6045TA; MPN Bourns SRN6045TA-4R7M
PF1: +9V
PF2: +9VA
PF3: +5V
PF4: +5V_SEED
PF5: +5V_ESP
PF6: +9VA_OPA
PF7: VIN_RAW
PF8: GND
R61, R62, R63, R64, R65: 1k; R_0805_2012Metric
R101, R201: 1M; R_0805_2012Metric
R102, R106, R202, R206, R304, R404, R504, R505: 10k; R_0805_2012Metric
R103, R108, R203, R208, R303, R403: 100R; R_0805_2012Metric
R104, R204: 3k3; R_0805_2012Metric
R105, R205: 4k7; R_0805_2012Metric
R107, R207: 6k8; R_0805_2012Metric
R301, R401: 15k; R_0805_2012Metric
R302, R402: 33k; R_0805_2012Metric
R501, R502, R503: 3R3; R_1206_3216Metric
RV1, RV2, RV3, RV4, RV5, RV6: B10k; Potentiometer_Alpha_RD901F-40-00D_Single_Vertical; MPN Alpha RD901F-40-15F-B10K
SW1: HP cut ON-OFF-ON; SW_Toggle_2M_SPDT_Vertical; MPN Dailywell 2MS3T1B1M2QES
SW2: LP cut ON-OFF-ON; SW_Toggle_2M_SPDT_Vertical; MPN Dailywell 2MS3T1B1M2QES
U1: Daisy Seed3; DAISY_SEED; MPN Electro-Smith Seed3
U2, U3, U4, U6: OPA1652AIDR; SOIC-8_3.9x4.9mm_P1.27mm; MPN TI OPA1652AIDR
U5: AP63205WU-7; TSOT-23-6; MPN Diodes AP63205WU-7

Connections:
+3V3A: RV1.1, RV2.1, RV3.1, RV4.1, RV5.1, RV6.1, U1.21 (3V3_A)
+5V: C508.1, C509.1, FB3.1, FB4.1, L1.2, PF3.1, U5.1 (FB)
+5V_ESP: C505.1, C512.1, FB4.2, J5.1, PF5.1
+5V_FB: FB3.2, R503.1
+5V_SEED: C504.1, C511.1, PF4.1, R503.2, U1.39 (VIN)
+9V: C501.1, C506.1, C507.1, FB1.2, PF1.1, R501.1, U5.2 (EN), U5.3 (IN)
+9VA: C503.1, FB2.1, PF2.1, R502.2
+9VA_OPA: C521.1, C522.1, C523.1, C524.1, FB2.2, PF6.1, R504.1, U2.8 (V+), U3.8 (V+), U4.8 (V+), U6.8 (V+)
+9V_RC1: C502.1, R501.2, R502.1
AREF: C514.1, R101.2, R201.2, U2.5 (+), U3.5 (+), U4.3 (+), U4.6 (-), U4.7, U6.3 (+), U6.5 (+)
AREF_DIV: C513.1, R504.2, R505.1, U4.5 (+)
BUCK_BST: C510.2, U5.6 (BST)
BUCK_SW: C510.1, L1.1, U5.5 (SW)
FS1: J11.1, U1.1 (D0)
FS2: J12.1, U1.2 (D1)
FS3: J13.1, U1.3 (D2)
FS4: J14.1, U1.4 (D3)
FS5: J15.1, U1.5 (D4)
GND: C102.2, C103.2, C106.2, C202.2, C203.2, C206.2, C501.2, C502.2, C503.2, C504.2, C505.2, C506.2, C507.2, C508.2, C509.2, C511.2, C512.2, C513.2, C514.2, C521.2, C522.2, C523.2, C524.2, D2.1 (A1), D21.1 (K), D22.1 (K), D23.1 (K), D24.1 (K), D25.1 (K), J1.1, J1.3, J2.S, J3.S, J5.2, J11.2, J12.2, J13.2, J14.2, J15.2, PF8.1, R102.2, R105.2, R202.2, R205.2, R304.2, R404.2, R505.2, RV1.3, RV2.3, RV3.3, RV4.3, RV5.3, RV6.3, SW1.2 (B), SW2.2 (B), U1.20 (AGND), U1.40 (DGND), U2.4 (V-), U3.4 (V-), U4.4 (V-), U5.4 (GND), U6.4 (V-)
HP_A: SW1.1 (A), U1.6 (D5)
HP_B: SW1.3 (C), U1.7 (D6)
IN_L_BIAS: C101.1, R101.1, R103.1
IN_L_BUF: R104.1, U2.1, U2.2 (-)
IN_L_CODEC: C106.1, R108.2, U1.16 (AUDIO_IN_1)
IN_L_DIV: C103.1, C104.2, R104.2, R105.1
IN_L_INN: C105.1, R106.2, R107.1, U2.6 (-)
IN_L_OPIN: C102.1, R103.2, U2.3 (+)
IN_L_S2IN: C104.1, R106.1
IN_L_S2OUT: C105.2, R107.2, R108.1, U2.7
IN_L_TIP: C101.2, J2.T
IN_L_TN: J2.TN, R102.1
IN_R_BIAS: C201.1, R201.1, R203.1
IN_R_BUF: R204.1, U3.1, U3.2 (-)
IN_R_CODEC: C206.1, R208.2, U1.17 (AUDIO_IN_2)
IN_R_DIV: C203.1, C204.2, R204.2, R205.1
IN_R_INN: C205.1, R206.2, R207.1, U3.6 (-)
IN_R_OPIN: C202.1, R203.2, U3.3 (+)
IN_R_S2IN: C204.1, R206.1
IN_R_S2OUT: C205.2, R207.2, R208.1, U3.7
IN_R_TIP: C201.2, J2.R
IN_R_TN: J2.RN, R202.1
KNOB1: RV1.2, U1.22 (D15)
KNOB2: RV2.2, U1.23 (D16)
KNOB3: RV3.2, U1.24 (D17)
KNOB4: RV4.2, U1.25 (D18)
KNOB5: RV5.2, U1.26 (D19)
KNOB6: RV6.2, U1.27 (D20)
LED1: R61.1, U1.10 (D9)
LED1_K: D21.2 (A), R61.2
LED2: R62.1, U1.11 (D10)
LED2_K: D22.2 (A), R62.2
LED3: R63.1, U1.12 (D11)
LED3_K: D23.2 (A), R63.2
LED4: R64.1, U1.13 (D12)
LED4_K: D24.2 (A), R64.2
LED5: R65.1, U1.33 (D26)
LED5_K: D25.2 (A), R65.2
LP_A: SW2.1 (A), U1.8 (D7)
LP_B: SW2.3 (C), U1.9 (D8)
OUT_L_AMP: C302.2, R302.2, R303.1, U4.1
OUT_L_C: C301.1, R301.1
OUT_L_DAC: C301.2, U1.18 (AUDIO_OUT_1)
OUT_L_INN: C302.1, R301.2, R302.1, U4.2 (-)
OUT_L_RC: C303.1, R303.2
OUT_L_TIP: C303.2, J3.T, R304.1
OUT_R_AMP: C402.2, R402.2, R403.1, U6.1
OUT_R_C: C401.1, R401.1
OUT_R_DAC: C401.2, U1.19 (AUDIO_OUT_2)
OUT_R_INN: C402.1, R401.2, R402.1, U6.2 (-)
OUT_R_RC: C403.1, R403.2
OUT_R_TIP: C403.2, J3.R, R404.1
U6B_OUT: U6.6 (-), U6.7
UART_SEED_RX: J6.7, U1.15 (D14)
UART_SEED_TX: J6.8, U1.14 (D13)
VIN_D: D1.1 (K), D2.2 (A2), FB1.1
VIN_F: D1.2 (A), F1.2
VIN_RAW: F1.1, J1.2, PF7.1

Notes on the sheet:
POWER 9V in -> PTC -> Schottky -> +9V; RC-filtered +9VA for op-amps; AP63205 buck -> +5V; LC-filtered +5V_SEED / +5V_ESP; AREF = 4.5 V (U4B)
OP-AMPS OPA1652 x4 (OPA1602 symbol, same pinout). U2: in L (A buffer, B inverting x-0.68) U3: in R U4: A out L, B AREF buffer U6: A out R, B spare
INPUT L jack tip -> 10u -> 1M to AREF -> 100R/100p -> buffer -> 3k3/4k7+1n -> 10u -> 10k -> inverting (6k8||470p) -> 100R/33n -> Seed AUDIO_IN_1
INPUT R (same as L) -> Seed AUDIO_IN_2
OUTPUT L Seed AUDIO_OUT_1 -> 10u -> 15k -> inverting x-2.2 (33k||100p) -> 100R -> 10u -> jack tip, 10k load
OUTPUT R
JACKS
CONTROLS 6 knobs (A0-A5), 2 ON-OFF-ON toggles (D5-D8), 5 footswitch headers (D0-D4), 5 LEDs (D9-D12, D26)
ESP32-C3 SuperMini socket (UART: Seed D13 -> IO20, Seed D14 <- IO21; 5V from +5V_ESP)
MECHANICAL
DAISY SEED3 (socketed; pins per firmware/daisy/main.cpp)

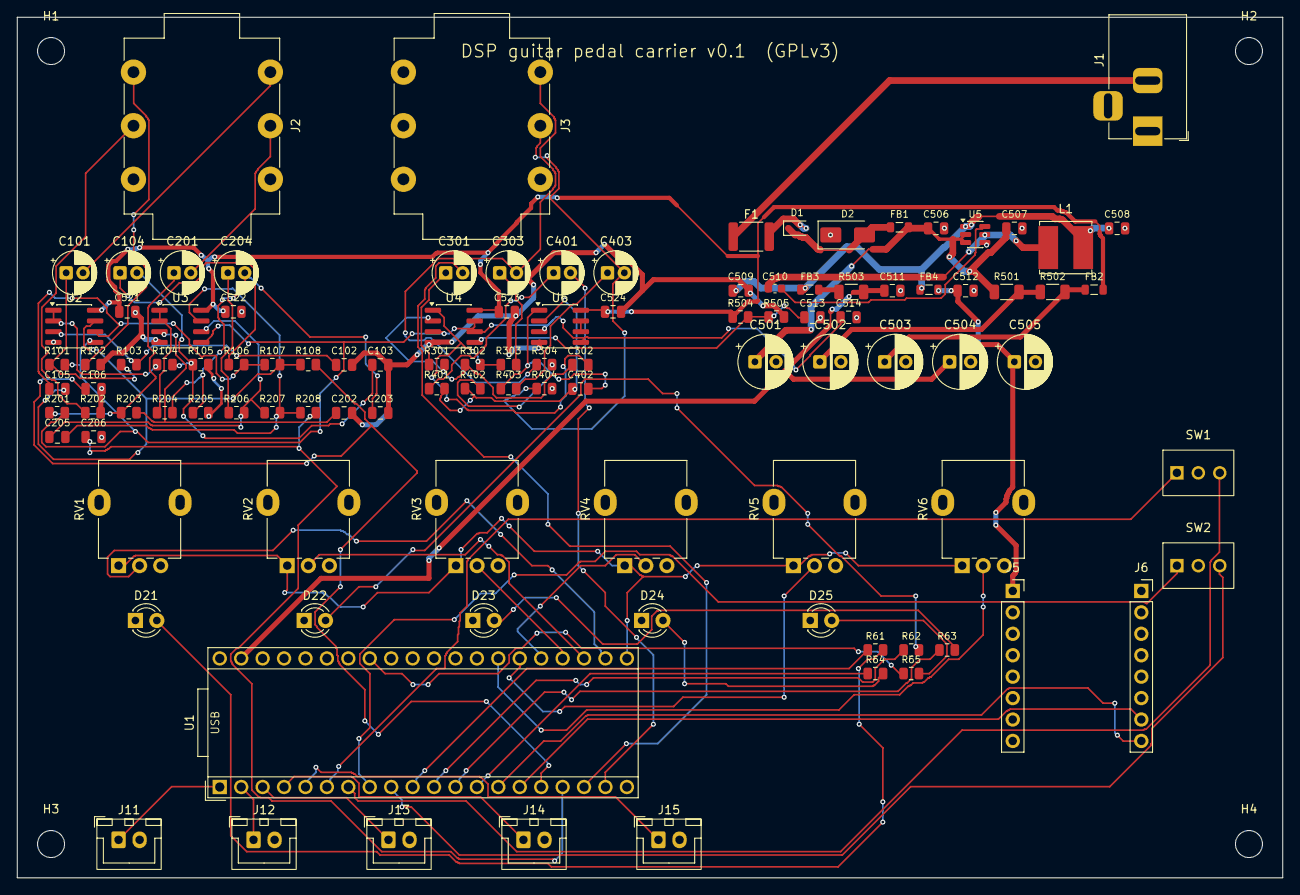
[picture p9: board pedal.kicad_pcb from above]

Board: 2 copper layers, 150.0 x 102.0 mm, 111 parts (0 on the bottom side), 77 nets.

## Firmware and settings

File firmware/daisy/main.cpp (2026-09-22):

// Daisy Seed3 wrapper around the portable DSP core.
// UNVERIFIED: written against libDaisy's public API but not compiled here (no arm-none-eabi toolchain on the dev machine).
//
// Pin map (Seed3 datasheet names) — keep in sync with hardware/kicad and docs/design.md §2
//   ADC A0..A5 (pins 22-27)  : knobs 1-6 (B10k, 3V3A -> GND)
//   D0..D3 (pins 1-4)        : effect footswitches 1-4  (SPST momentary to GND, internal pull-up)
//   D4 (pin 5)               : TAP footswitch
//   D5,D6 (pins 6,7)         : global HP toggle (ON-OFF-ON: two contacts to GND)
//   D7,D8 (pins 8,9)         : global LP toggle
//   D9..D12 (pins 10-13)     : effect LEDs 1-4 ; D26 (pin 33): tempo LED
//   D13/D14 (pins 14/15)     : USART1 TX/RX <-> ESP32-C3 (MIDI bytes, 115200 8N1)
//   D27 (pin 34)             : input jack ring switch (stereo plug present, to GND)
#include "daisy_seed.h"
#include "pedal/pedal.h"
#include "pedal/midi.h"

using namespace daisy;

static DaisySeed hw;

// ---- SDRAM arena for the DSP core ----
static uint8_t DSY_SDRAM_BSS sdramArena[4 * 1024 * 1024];
class SdramAllocator final : public pedal::Allocator {
public:
    void* alloc(size_t bytes, size_t align) override {
        size_t p = (used_ + align - 1) & ~(align - 1);
        if (p + bytes > sizeof(sdramArena)) return nullptr;
        used_ = p + bytes; return sdramArena + p;
    }
private:
    size_t used_ = 0;
};

static SdramAllocator mem;
static pedal::Pedal   pedalCore;
static pedal::MidiParser midi(pedalCore);
static UartHandler    uart;
static CpuLoadMeter   loadMeter;
static pedal::Frame   block[pedal::kMaxBlock];
constexpr int kBlock = 48;   // 1 ms @ 48 kHz

// ---- controls ----
static Switch fxSw[4], tapSw, hpUp, hpDn, lpUp, lpDn, ringSw;
static GPIO   led[4], tempoLed;
static AnalogControl knob[6];
static int   bank = 3;                   // effect edited by the knob bank
static bool  knobCaught[6] = { true, true, true, true, true, true };
static float knobLast[6] = {};
static uint32_t tapDownMs = 0; static bool selectMode = false;

// echo state changes to the ESP32 so BLE/web clients stay in sync
class UartEcho final : public pedal::PedalListener {
public:
    void onParamChanged(int e, int p, float n) override { uint8_t b[6]; send(b, pedal::MidiParser::encodeParamCC(e, p, n, b)); }
    void onEnabledChanged(int e, bool on) override      { uint8_t b[3]; send(b, pedal::MidiParser::encodeEnableCC(e, on, b)); }
    void onOrderChanged(const uint8_t* o) override      { uint8_t b[8]; send(b, pedal::MidiParser::encodeOrder(o, b)); }
    void onTempoChanged(float spb) override             { uint8_t b[6]; send(b, pedal::MidiParser::encodeTempo(spb, b)); }
    void onPresetRequest(bool save, int slot) override;
private:
    void send(const uint8_t* b, int n) { uart.BlockingTransmit(const_cast<uint8_t*>(b), n, 10); }
} echo;

// ---- presets in QSPI ----
struct PresetBank { pedal::Preset slots[8]; };
static PersistentStorage<PresetBank> storage(hw.qspi);
void UartEcho::onPresetRequest(bool save, int slot) {
    if (slot < 0 || slot >= 8) return;
    auto& bankData = storage.GetSettings();
    if (save) { pedalCore.toPreset(bankData.slots[slot]); storage.Save(); }
    else if (pedalCore.applyPreset(bankData.slots[slot])) {
        uint8_t dump[pedal::MidiParser::kDumpMax]; const int n = pedal::MidiParser::encodeStateDump(pedalCore, dump);
        uart.BlockingTransmit(dump, n, 50);
    }
}

static void AudioCallback(AudioHandle::InputBuffer in, AudioHandle::OutputBuffer out, size_t size) {
    loadMeter.OnBlockStart();
    for (size_t i = 0; i < size; ++i) block[i] = { in[0][i], in[1][i] };
    pedalCore.process(block, static_cast<int>(size));
    for (size_t i = 0; i < size; ++i) { out[0][i] = block[i].l; out[1][i] = block[i].r; }
    loadMeter.OnBlockEnd();
}

static int toggleState(Switch& up, Switch& dn) { return up.Pressed() ? 1 : (dn.Pressed() ? 2 : 0); }

static void pollControls() {
    for (auto& s : fxSw) s.Debounce();
    tapSw.Debounce(); hpUp.Debounce(); hpDn.Debounce(); lpUp.Debounce(); lpDn.Debounce(); ringSw.Debounce();
    const uint32_t now = System::GetNow();

    // TAP: press = tap tempo; hold 500 ms = select mode; hold 3 s (with fx1+fx4) = DFU
    if (tapSw.RisingEdge()) tapDownMs = now;
    if (tapSw.Pressed() && !selectMode && now - tapDownMs > 500) selectMode = true;
    if (tapSw.FallingEdge()) { if (!selectMode) pedalCore.tap(pedalCore.samplePosition()); selectMode = false; }
    if (fxSw[0].Pressed() && fxSw[3].Pressed() && fxSw[0].TimeHeldMs() > 2000 && fxSw[3].TimeHeldMs() > 2000) System::ResetToBootloader();

    for (int e = 0; e < 4; ++e) if (fxSw[e].RisingEdge()) {
        if (selectMode) { bank = e; for (auto& c : knobCaught) c = false; }
        else pedalCore.toggle(e);
    }
    static int lastHp = -1, lastLp = -1;
    const int hpS = toggleState(hpUp, hpDn), lpS = toggleState(lpUp, lpDn);
    if (hpS != lastHp) { lastHp = hpS; pedalCore.setGlobalHp(hpS); }
    if (lpS != lastLp) { lastLp = lpS; pedalCore.setGlobalLp(lpS); }
    pedalCore.setStereoInput(ringSw.Pressed());

    // knobs with soft take-over
    for (int k = 0; k < 6; ++k) {
        knob[k].Process();
        const float v = knob[k].Value();
        if (k >= pedalCore.effect(bank)->numParams()) continue;
        const float cur = pedalCore.getParam(bank, k);
        if (!knobCaught[k]) { if ((knobLast[k] - cur) * (v - cur) <= 0.f || fabsf(v - cur) < 0.01f) knobCaught[k] = true; }
        if (knobCaught[k] && fabsf(v - cur) > 0.002f) pedalCore.setParam(bank, k, v);
        knobLast[k] = v;
    }
    for (int e = 0; e < 4; ++e) led[e].Write(selectMode ? (e == bank && (now / 100) % 2) : pedalCore.isEnabled(e));
    const float beatPos = fmodf(static_cast<float>(pedalCore.samplePosition()) / 48000.f, pedalCore.tempo());
    tempoLed.Write(beatPos < 0.08f);
}

int main() {
    hw.Init(true);   // boost to 480 MHz
    hw.StartLog(false);   // serial log for the cpu line below (no wait for a host)
    hw.SetAudioBlockSize(kBlock);
    hw.SetAudioSampleRate(SaiHandle::Config::SampleRate::SAI_48KHZ);

    pedal::Config cfg; cfg.sampleRate = hw.AudioSampleRate(); cfg.blockSize = kBlock; cfg.mem = &mem;
    pedalCore.init(cfg);
    pedalCore.setListener(&echo);

    // controls
    const Pin fxPins[4] = { seed::D0, seed::D1, seed::D2, seed::D3 };
    for (int e = 0; e < 4; ++e) fxSw[e].Init(fxPins[e], 1000.f);
    tapSw.Init(seed::D4, 1000.f); hpUp.Init(seed::D5, 1000.f); hpDn.Init(seed::D6, 1000.f); lpUp.Init(seed::D7, 1000.f); lpDn.Init(seed::D8, 1000.f);
    ringSw.Init(seed::D27, 1000.f);
    const Pin ledPins[4] = { seed::D9, seed::D10, seed::D11, seed::D12 };
    for (int e = 0; e < 4; ++e) led[e].Init(ledPins[e], GPIO::Mode::OUTPUT);
    tempoLed.Init(seed::D26, GPIO::Mode::OUTPUT);
    AdcChannelConfig adcCfg[6]; const Pin knobPins[6] = { seed::A0, seed::A1, seed::A2, seed::A3, seed::A4, seed::A5 };
    for (int k = 0; k < 6; ++k) adcCfg[k].InitSingle(knobPins[k]);
    hw.adc.Init(adcCfg, 6); hw.adc.Start();
    for (int k = 0; k < 6; ++k) knob[k].Init(hw.adc.GetPtr(k), 1000.f);

    // UART to the ESP32-C3
    UartHandler::Config ucfg; ucfg.baudrate = 115200; ucfg.periph = UartHandler::Config::Peripheral::USART_1;
    ucfg.pin_config.tx = seed::D13; ucfg.pin_config.rx = seed::D14;
    uart.Init(ucfg);
    static uint8_t rxBuf[256]; uart.DmaReceiveFifo();   // libDaisy FIFO receive (v7+)

    // presets
    PresetBank def; for (auto& s : def.slots) pedal::Pedal::defaultPreset(s);
    storage.Init(def);
    pedalCore.applyPreset(storage.GetSettings().slots[0]);

    loadMeter.Init(hw.AudioSampleRate(), kBlock);
    hw.StartAudio(AudioCallback);

    uint32_t lastLog = 0;
    while (true) {
        pollControls();
        while (uart.Readable()) midi.feed(uart.PopRx());
        if (midi.stateRequested()) { uint8_t dump[pedal::MidiParser::kDumpMax]; uart.BlockingTransmit(dump, pedal::MidiParser::encodeStateDump(pedalCore, dump), 50); }
        const uint32_t now = System::GetNow();
        if (now - lastLog > 1000) { lastLog = now; hw.PrintLine("cpu avg %d%% max %d%%", static_cast<int>(loadMeter.GetAvgCpuLoad() * 100.f), static_cast<int>(loadMeter.GetMaxCpuLoad() * 100.f)); }
        System::Delay(1);
    }
}

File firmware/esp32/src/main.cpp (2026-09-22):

// ESP32-C3 radio co-processor. One control protocol everywhere: MIDI bytes.
//   BLE-MIDI peripheral  <->  UART1 (to Daisy USART1, 115200)  <->  WebSocket clients (JSON <-> MIDI)
// BLE is always on. The WiFi AP starts on a request from the Daisy (TAP held 3 s sends
// SysEx 7D 20) or at boot if WIFI_AT_BOOT is defined. Web UI lives in LittleFS (/index.html,
// built from ../../web). OTA: ArduinoOTA on the AP (hostname "pedal").
#include <Arduino.h>
#include <WiFi.h>
#include <ESPAsyncWebServer.h>
#include <LittleFS.h>
#include <ArduinoOTA.h>
#include <BLEMidi.h>

static const int PIN_TX = 21, PIN_RX = 20;     // C3 SuperMini UART1
static HardwareSerial daisy(1);
static AsyncWebServer server(80);
static AsyncWebSocket ws("/ws");
static bool wifiUp = false;
void startWifi();

// ---- MIDI <-> JSON for the web UI ----
// {"cc":8,"v":64}  {"cc":8,"v14":8192}  {"on":2,"v":1}  {"order":[3,0,1,2]}  {"hp":{"slot":0,"hz":80}}  {"lp":..}  {"tap":1}
// {"preset":{"save":true,"slot":2}}  {"tempo_ms":500}  {"req":"state"}
static void sendToDaisy(const uint8_t* b, size_t n) { daisy.write(b, n); }

static void jsonToMidi(const String& s) {
    // tiny hand parser: enough for the fixed message set above, no ArduinoJson dependency
    auto num = [&](const char* key, long def = -1) -> long { int i = s.indexOf(String("\"") + key + "\""); if (i < 0) return def; i = s.indexOf(':', i); return s.substring(i + 1).toInt(); };
    uint8_t b[16];
    if (s.indexOf("\"v14\"") >= 0) { const int cc = num("cc"), v = num("v14"); b[0] = 0xB0; b[1] = cc; b[2] = (v >> 7) & 0x7F; b[3] = 0xB0; b[4] = cc + 32; b[5] = v & 0x7F; sendToDaisy(b, 6); }
    else if (s.indexOf("\"cc\"") >= 0) { b[0] = 0xB0; b[1] = num("cc"); b[2] = num("v") & 0x7F; sendToDaisy(b, 3); }
    else if (s.indexOf("\"on\"") >= 0) { b[0] = 0xB0; b[1] = 64 + num("on"); b[2] = num("v") ? 127 : 0; sendToDaisy(b, 3); }
    else if (s.indexOf("\"order\"") >= 0) { int i = s.indexOf('['); b[0] = 0xF0; b[1] = 0x7D; b[2] = 0x01; for (int k = 0; k < 4; ++k) { b[3 + k] = s.substring(i + 1).toInt(); i = s.indexOf(',', i + 1); } b[7] = 0xF7; sendToDaisy(b, 8); }
    else if (s.indexOf("\"hp\"") >= 0 || s.indexOf("\"lp\"") >= 0) { const int hz = num("hz"); b[0] = 0xF0; b[1] = 0x7D; b[2] = s.indexOf("\"lp\"") >= 0 ? 0x05 : 0x04; b[3] = num("slot"); b[4] = (hz >> 7) & 0x7F; b[5] = hz & 0x7F; b[6] = 0xF7; sendToDaisy(b, 7); }
    else if (s.indexOf("\"tap\"") >= 0) { b[0] = 0xB0; b[1] = 72; b[2] = 127; sendToDaisy(b, 3); }
    else if (s.indexOf("\"tempo_ms\"") >= 0) { const int ms = num("tempo_ms"); b[0] = 0xF0; b[1] = 0x7D; b[2] = 0x06; b[3] = (ms >> 7) & 0x7F; b[4] = ms & 0x7F; b[5] = 0xF7; sendToDaisy(b, 6); }
    else if (s.indexOf("\"preset\"") >= 0) { b[0] = 0xF0; b[1] = 0x7D; b[2] = s.indexOf("true") >= 0 ? 0x02 : 0x03; b[3] = num("slot"); b[4] = 0xF7; sendToDaisy(b, 5); }
    else if (s.indexOf("\"req\"") >= 0) { b[0] = 0xF0; b[1] = 0x7D; b[2] = 0x07; b[3] = 0xF7; sendToDaisy(b, 4); }
}

// Daisy -> clients: forward raw MIDI to BLE and as JSON to WebSocket
static uint8_t rxStatus = 0; static int rxD1 = -1; static bool inSx = false; static uint8_t sx[64]; static int sxLen = 0;
static void midiFromDaisy(uint8_t c) {
    if (c == 0xF0) { inSx = true; sxLen = 0; return; }
    if (c == 0xF7) { inSx = false; if (sxLen >= 2 && sx[0] == 0x7D) {
            if (sx[1] == 0x01 && sxLen >= 6) ws.textAll(String("{\"order\":[") + sx[2] + "," + sx[3] + "," + sx[4] + "," + sx[5] + "]}");
            else if ((sx[1] == 0x04 || sx[1] == 0x05) && sxLen >= 5) ws.textAll(String("{\"") + (sx[1] == 0x05 ? "lp" : "hp") + "\":{\"slot\":" + sx[2] + ",\"hz\":" + ((sx[3] << 7) | sx[4]) + "}}");
            else if (sx[1] == 0x06 && sxLen >= 4) ws.textAll(String("{\"tempo_ms\":") + ((sx[2] << 7) | sx[3]) + "}");
            else if (sx[1] == 0x20) { startWifi(); }
        }
        return; }
    if (inSx) { if (sxLen < 64) sx[sxLen++] = c; return; }
    if (c & 0x80) { rxStatus = c; rxD1 = -1; return; }
    if (rxD1 < 0) { rxD1 = c; return; }
    if ((rxStatus & 0xF0) == 0xB0) {
        const uint8_t cc = rxD1, v = c; rxD1 = -1;
        BLEMidiServer.controlChange(0, cc, v);
        if (cc < 64) ws.textAll(String("{\"cc\":") + cc + ",\"v\":" + v + "}");
        else if (cc < 68) ws.textAll(String("{\"on\":") + (cc - 64) + ",\"v\":" + (v >= 64) + "}");
        else ws.textAll(String("{\"cc\":") + cc + ",\"v\":" + v + "}");
    } else rxD1 = -1;
}

void startWifi() {
    if (wifiUp) return;
    WiFi.mode(WIFI_AP); WiFi.softAP("pedal", "guitarfuzz");
    ArduinoOTA.setHostname("pedal"); ArduinoOTA.begin();
    server.begin(); wifiUp = true;
}

void setup() {
    Serial.begin(115200);
    daisy.begin(115200, SERIAL_8N1, PIN_RX, PIN_TX);
    LittleFS.begin(true);
    BLEMidiServer.begin("Pedal");
    BLEMidiServer.setControlChangeCallback([](uint8_t, uint8_t cc, uint8_t v, uint16_t) { uint8_t b[3] = { 0xB0, cc, v }; sendToDaisy(b, 3); });
    BLEMidiServer.setProgramChangeCallback([](uint8_t, uint8_t p, uint16_t) { uint8_t b[2] = { 0xC0, p }; sendToDaisy(b, 2); });
    ws.onEvent([](AsyncWebSocket*, AsyncWebSocketClient* c, AwsEventType t, void*, uint8_t* data, size_t len) {
        if (t == WS_EVT_CONNECT) { uint8_t b[4] = { 0xF0, 0x7D, 0x07, 0xF7 }; sendToDaisy(b, 4); }
        else if (t == WS_EVT_DATA) jsonToMidi(String(reinterpret_cast<char*>(data), len));
    });
    server.addHandler(&ws);
    server.serveStatic("/", LittleFS, "/").setDefaultFile("index.html");
    server.onNotFound([](AsyncWebServerRequest* r) { r->redirect("/"); });   // captive-portal style
#ifdef WIFI_AT_BOOT
    startWifi();
#endif
}

void loop() {
    while (daisy.available()) midiFromDaisy(daisy.read());
    if (wifiUp) ArduinoOTA.handle();
    ws.cleanupClients();
}

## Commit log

2026-09-22 DSP guitar pedal: core, emulator, SPICE validation, KiCad carrier board, CI
    Portable DSP core (tremolo/delay/reverb/fuzz, chain, MIDI map), macOS emulator
    (CLI + JUCE panel with loop player, keyboard sampler, BPM entry), hardware model
    validated against ngspice, KiCad schematic/PCB generated from one netlist and
    routed with KiCadRoutingTools (0 DRC errors), Daisy/ESP32 firmware wrappers
    (uncompiled), GitHub Actions matrix for Windows/macOS binaries.
    [bom.csv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]
2026-09-22 Docs: status handover and learnings log
    STATUS.md records what is verified vs unverified, the next steps (Roman's Windows
    test, hardware Phase A, missing toolchains, board review before ordering) and how to
    resume. LEARNINGS.md records the findings that checks caught rather than reasoning:
    the input-stage divider loading error, the codec abs-max/full-scale conflation, the
    reversed coupling caps, the bypass-trails dry attenuation, the macOS mic-permission
    and repaint-hang traps, and the Windows dynamic-CRT packaging defect.
    Claude-Session: https://claude.ai/code/session_01LSExyZUkUe9U54KgE3hmg8
2026-09-30 Emulator: mono live input sums inputs 1+2 instead of dropping input 2
    A guitar on an interface's second jack (e.g. Volt 2 input 2) was silent with
    'TS plug (mono)' ticked: mono mode copied the left channel into both sides.
    Now the live input folds L+R in mono. The source label shows per-input peaks
    so a remote user can see where their signal lands. Harness regression test.
2026-09-30 Emulator: flag a dead live input; Windows exclusive-mode troubleshooting
    A Volt 2 in 'Windows Audio' (shared) mode delivered pure digital silence while
    the device looked correctly selected; 'Windows Audio (Exclusive Mode)' fixed it.
    The processor now counts consecutive samples below -120 dBFS on the live input,
    and after 3 s the source line shows a warning pointing at that setting.
    Harness covers both the reset and the detection.
    [PluginProcessor.cpp]

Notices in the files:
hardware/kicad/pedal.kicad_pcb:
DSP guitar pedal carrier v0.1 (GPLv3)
